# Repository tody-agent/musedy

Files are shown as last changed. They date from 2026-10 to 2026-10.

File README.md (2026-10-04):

# 🤖 Musedy S3 - Robot Trí Tuệ Nhân Tạo Mini (Retro AI Companion)







**Musedy S3** là robot trí tuệ nhân tạo để bàn thế hệ mới, kết hợp hoàn hảo giữa hình hài máy tính cổ điển Macintosh CRT thập niên 80 (màu Xanh Dương & Trắng Sữa) với bộ vi xử lý lõi kép **ESP32-S3 N16R8**:
- 🗣️ **Voice Wakeup kích hoạt tức thì:** Nhận diện từ khóa giọng nói ("Rody ơi" / "Musedy") và tự động ngắt lời (Barge-in).
- 🎙️ **Giọng nói tiếng Việt mượt mà:** Tích hợp engine Zero-Token Edge TTS & Google Translate TTS, không tốn chi phí API token.
- 📺 **Màn hình 1.8" TFT 160x128 Xoay Ngang (ST7735 / ST7789):** Tỉ lệ hiển thị ngang 5:4 chuẩn cho khung vỏ máy tính retro, và tùy chọn 1.28" tròn GC9A01 240x240, 30 FPS mượt mà.
- 🔊 **Âm học loa vòm 3W dội sàn:** Mạch giải mã I2S MAX98357A kết hợp buồng kín chống đoản mạch âm, cho chất âm trầm ấm rõ tiếng.
- 📐 **Hỗ trợ 2 phong cách vỏ in 3D:** Mẫu Máy Tính Retro Xiaozhi Computer Edition (kèm ngàm in 3D `cad/stl/musedy_computer_18_adapter.stl`) & Quả Cầu Astro-Pod.

---

## 🌐 Trải Nghiệm Trực Tuyến & Tài Liệu Nhanh

- 🚀 **Trang chủ & Giả lập Simulator trực tiếp:** [https://tody-agent.github.io/musedy/](https://tody-agent.github.io/musedy/)
- ⚡ **Sơ đồ kết nối phần cứng & Pinout:** [https://tody-agent.github.io/musedy/wiring.html](https://tody-agent.github.io/musedy/wiring.html) (File Markdown: [`docs/WIRING_DIAGRAM.md`](docs/WIRING_DIAGRAM.md))
- 🛠️ **Cẩm nang triển khai & nạp firmware:** [https://tody-agent.github.io/musedy/deploy.html](https://tody-agent.github.io/musedy/deploy.html) (File Markdown: [`docs/DEPLOYMENT_GUIDE.md`](docs/DEPLOYMENT_GUIDE.md))
- 🖥️ **Hướng dẫn lắp vỏ máy tính cổ điển:** [`docs/XIAOZHI_COMPUTER_GUIDE.md`](docs/XIAOZHI_COMPUTER_GUIDE.md)
- 🛸 **Hướng dẫn lắp quả cầu Astro-Pod:** [`docs/ASSEMBLY_GUIDE.md`](docs/ASSEMBLY_GUIDE.md)

---

## ⚡ Sơ Đồ Chân Kết Nối (Hardware Pinout)

| Thiết Bị | Chân Module | Chân ESP32-S3 | Ghi Chú Kỹ Thuật |
| :--- | :--- | :---: | :--- |
| **Màn Hình 1.8" / GC9A01** | SCLK / MOSI / DC / RST / CS / BLK | **42, 41, 40, 39, 38, 21** | 160x128 Landscape ST7735 / 240x240 GC9A01, SPI Master 40MHz, PWM Backlight |
| **Micro I2S INMP441** | WS / SCK / SD / L/R | **4, 5, 6, GND** | Kênh Trái (Left Channel), thu âm đa hướng |
| **Ampli MAX98357A** | BCLK / LRC / DIN / VIN | **15, 16, 7, 5V (VBUS)** | Nguồn 5V cho công suất 3W RMS (Loa 4Ω) |
| **6-DOF IMU MPU6050** | SDA / SCL | **8, 9** | I2C0 Master, nhận diện nghiêng/lắc/rơi |
| **Cảm Ứng Đỉnh Đầu** | Chạm điện dung | **GPIO 2** | Vuốt chạm tương tác cảm xúc |
| **Nút Bấm** | BOOT (Talk) / Aux Menu | **GPIO 0, GPIO 47** | Nhấn nói chuyện / BLE Pairing |

---

## 🚀 Hướng Dẫn Bắt Đầu Nhanh (Quick Start)

### 1. Kiểm thử mã nguồn trước trên máy tính (181 tests)
```bash
git clone https://github.com/tody-agent/musedy.git
cd musedy

# Chạy toàn bộ 181 test tự động không cần cắm mạch:
DEVELOPER_DIR=/Library/Developer/CommandLineTools ./test_host.sh
```

### 2. Cấu hình thiết bị & nạp firmware qua ESP-IDF
```bash
# Thiết lập target ESP32-S3
idf.py set-target esp32s3

# Áp dụng cấu hình chuẩn Musedy Computer (Màn hình 1.8" TFT 160x128 Xoay Ngang)
cp devices/sdkconfig.muse-computer-18 sdkconfig

# Biên dịch mã nguồn
idf.py build

# Nạp vào mạch và mở Serial Monitor
idf.py -p /dev/cu.usbmodem1101 flash monitor
```

### 3. Cấu hình Wi-Fi nhanh qua Serial
Khi mở Serial Monitor (115200 baud), gửi lệnh:
```text
>wifi=Ten_Wifi_Cua_Ban,Mat_Khau_Wifi
>say=Xin chào! Mình là robot Musedy!
```

---

## 🧩 Cấu Trúc Dự Án (Repository Architecture)

```
musedy/
├── index.html                   # Landing page chính trên GitHub Pages
├── wiring.html                  # Sơ đồ kết nối phần cứng tương tác
├── deploy.html                  # Cẩm nang triển khai & lệnh nạp firmware
├── docs/                        # Tài liệu chi tiết & ảnh render
│   ├── WIRING_DIAGRAM.md        # Sơ đồ đấu nối chi tiết
│   ├── DEPLOYMENT_GUIDE.md      # Hướng dẫn build & flash
│   ├── XIAOZHI_COMPUTER_GUIDE.md # Cẩm nang vỏ máy tính màu xanh dương
│   ├── ASSEMBLY_GUIDE.md        # Hướng dẫn lắp ráp quả cầu Astro-Pod
│   └── designs/                 # Bản vẽ và hình render 3D
├── cad/                         # File thiết kế tham số OpenSCAD
│   ├── xiaozhi_gc9a01_adapter.scad # Ngàm chuyển màn hình tròn CRT
│   └── rody_s3_astropod.scad    # Quả cầu Astro-Pod nguyên khối
├── Computer/                    # File in 3D STL vỏ máy tính retro
├── components/                  # Các module phần cứng ESP-IDF (muse, GC9A01, audio)
├── devices/                     # Cấu hình overlay cho từng dòng phần cứng
├── main/                        # Điểm khởi chạy firmware ESP32-S3
├── test_host.sh                 # Runner chạy 174 bài test tự động
└── tests/                       # Bộ kiểm thử dung sai, driver và thuật toán
```

---

## 📜 Giấy Phép & Tác Quyền

- Mã nguồn firmware phát triển theo giấy phép mã nguồn mở **Apache-2.0**.
- Thiết kế vỏ máy tính cổ điển mini bởi **董老爺 (Mr. Dong)** trên [MakerWorld #1967811](https://makerworld.com/en/models/1967811-xiaozhi-ai-computer-xiaozhi#profileId-2115633).
- Ngôn ngữ thiết kế web & UI tuân thủ hệ thống thiết kế **Meta Astryx**.

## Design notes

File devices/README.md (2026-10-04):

<!--
Copyright (c) Meta Platforms, Inc. and affiliates.

Licensed under the Apache License, Version 2.0 (the "License");
you may not use this file except in compliance with the License.
You may obtain a copy of the License at

    http://www.apache.org/licenses/LICENSE-2.0

Unless required by applicable law or agreed to in writing, software
distributed under the License is distributed on an "AS IS" BASIS,
WITHOUT WARRANTIES OR CONDITIONS OF ANY KIND, either express or implied.
See the License for the specific language governing permissions and
limitations under the License.
-->

# Devices

These are the boards the ESP32 Device SDK runs on. Each board is an `sdkconfig`
overlay: a short file of settings loaded on top of
[`../sdkconfig.defaults`](../sdkconfig.defaults) that picks the chip, flash,
memory, button, and how the device shows its status. The ESP32-C5 DevKitC-1 is
the default and needs no overlay.

Every board pairs with the Muse app, joins your Wi-Fi, and holds an encrypted
session to Muse. The rest depends on the hardware.

## Supported devices

| Board | Chip | Display | Flash / PSRAM | Reference | Buy |
|---|---|---|---|---|---|
| **ESP32-C5 DevKitC-1** | ESP32-C5 | None (RGB status light) | 8 MB / 8 MB | [Espressif docs](https://docs.espressif.com/projects/esp-dev-kits/en/latest/esp32c5/esp32-c5-devkitc-1/index.html) | [DigiKey](https://www.digikey.com/en/products/result?keywords=ESP32-C5-DevKitC-1) |
| **ideaspark ESP32 with 1.9" display** | ESP32 | 1.9" 170×320 LCD | 16 MB / none | — | [Amazon](https://www.amazon.com/s?k=ideaspark+ESP32+1.9+inch+ST7789) |
| **Seeed SenseCAP Indicator** | ESP32-S3 | 4" 480×480 LCD | 8 MB / 8 MB | [Seeed wiki](https://wiki.seeedstudio.com/SenseCAP_Indicator_Get_Started/) | [Seeed Studio](https://www.seeedstudio.com/SenseCAP-Indicator-D1-p-5643.html) |
| **Seeed reTerminal E1001** | ESP32-S3 | 7.5" 800×480 black and white e-paper | 32 MB / 8 MB | [Seeed wiki](https://wiki.seeedstudio.com/getting_started_with_reterminal_e1001/) | [Seeed Studio](https://www.seeedstudio.com/reTerminal-E1001-p-6534.html) |
| **Home Assistant Voice Preview Edition** | ESP32-S3 | None (12-LED ring) | 16 MB / 8 MB | [ESPHome repo](https://github.com/esphome/home-assistant-voice-pe) | [Home Assistant](https://www.home-assistant.io/voice-pe/) |
| **Waveshare ESP32-S3-Touch-AMOLED-1.75C** | ESP32-S3 | 1.75" 466×466 round AMOLED, touch | 32 MB / 8 MB | [Waveshare wiki](https://www.waveshare.com/wiki/ESP32-S3-Touch-AMOLED-1.75C), [GitHub](https://github.com/waveshareteam/ESP32-S3-Touch-AMOLED-1.75C) | [Waveshare](https://www.waveshare.com/esp32-s3-touch-amoled-1.75c.htm) |
| **Waveshare ESP32-S3-Touch-AMOLED-1.75** | ESP32-S3 | 1.75" 466×466 round AMOLED, touch | 16 MB / 8 MB | [Waveshare wiki](https://www.waveshare.com/wiki/ESP32-S3-Touch-AMOLED-1.75), [GitHub](https://github.com/waveshareteam/ESP32-S3-Touch-AMOLED-1.75) | [Waveshare](https://www.waveshare.com/esp32-s3-touch-amoled-1.75.htm) |
| **Espressif ESP32-S3-BOX-3** | ESP32-S3 | 2.4" 320×240 LCD, touch | 16 MB / 16 MB | [Espressif BSP](https://github.com/espressif/esp-bsp/tree/master/bsp/esp-box-3), [ESP-BOX](https://github.com/espressif/esp-box) | — |
| **AIPI Lite** | ESP32-S3 | 128×128 LCD | 16 MB / 8 MB | [xiaozhi-esp32 board](https://github.com/78/xiaozhi-esp32/tree/main/main/boards/xorigin/aipi-lite) | [AliExpress](https://www.aliexpress.com/w/wholesale-aipi-lite.html) |
| **Waveshare ESP32-C6-Touch-AMOLED-1.8** | ESP32-C6 | 1.8" 368×448 AMOLED, touch | 16 MB / none | [Waveshare wiki](https://www.waveshare.com/wiki/ESP32-C6-Touch-AMOLED-1.8) | [Waveshare](https://www.waveshare.com/esp32-c6-touch-amoled-1.8.htm) |
| **Seeed SenseCAP Watcher** | ESP32-S3 | 1.45" 412×412 round LCD, touch | 32 MB / 8 MB | [Seeed wiki](https://wiki.seeedstudio.com/watcher/), [GitHub](https://github.com/Seeed-Studio/SenseCAP-Watcher-Firmware) | [Seeed Studio](https://www.seeedstudio.com/SenseCAP-Watcher-W1-A-p-5979.html) |
| **M5Stack Cardputer ADV (experimental)** | ESP32-S3 | 1.14" 240×135 LCD | 8 MB / none | [M5Stack docs](https://docs.m5stack.com/en/core/Cardputer-Adv) | — |
| **M5Stack StickS3** | ESP32-S3 | 1.14" 135×240 LCD | 8 MB / 8 MB | [M5Stack docs](https://docs.m5stack.com/en/core/StickS3), [M5Unified](https://github.com/m5stack/M5Unified) | [M5Stack](https://shop.m5stack.com/products/m5sticks3-esp32s3-mini-iot-dev-kit) |
| **M5Stack StopWatch** | ESP32-S3 | 1.75" 466×466 round AMOLED, touch | 16 MB / 8 MB | [M5Stack docs](https://docs.m5stack.com/en/core/StopWatch), [M5Unified](https://github.com/m5stack/M5Unified), [factory firmware](https://github.com/m5stack/M5StopWatch-UserDemo) | — |
| **M5Stack StickC Plus2** | ESP32 | 1.14" 135×240 LCD | 8 MB / 2 MB | [M5Stack docs](https://docs.m5stack.com/en/core/M5StickC%20PLUS2), [M5Unified](https://github.com/m5stack/M5Unified) | [M5Stack](https://shop.m5stack.com/products/m5stickc-plus2-esp32-mini-iot-development-kit) (end of life) |

## Features

| | DevKitC-1 | ideaspark | SenseCAP Indicator | reTerminal E1001 | HA Voice PE | Waveshare S3 1.75C | Waveshare S3 1.75 | AIPI Lite | Waveshare C6 1.8 | Watcher | StickS3 | StickC Plus2 | Cardputer ADV | BOX-3 | StopWatch |
|---|:-:|:-:|:-:|:-:|:-:|:-:|:-:|:-:|:-:|:-:|:-:|:-:| :-: | :-: |:-:|
| Home-network tunnel | ✅ | — | ✅ | ✅ | ✅ | ✅ | ✅ | ✅ | — | ✅ | ✅ | ✅ | — | ✅ | ✅ |
| Shows status on | Light | Screen | Screen | E-paper | Light ring | Avatar | Avatar | Avatar | Avatar | Avatar | Avatar | Avatar | Avatar | Avatar | Avatar |
| Images from Muse | — | ✅ | ✅ | Black and white | — | ✅ | ✅ | ✅ | — | ✅ | ✅ | ✅ | — | ✅ | ✅ |
| UI and settings | — | — | — | — | — | ✅ | ✅ | ✅ | ✅ | ✅ | ✅ | ✅ | Experimental | ✅ | ✅ |
| Push-to-talk | — | — | — | — | ✅ | ✅ | ✅ | ✅ | Text replies | ✅ | ✅ | ✅ | Text replies (experimental) | ✅ | ✅ |
| Speaker and mic | — | — | — | — | ✅ | ✅ | ✅ | ✅ | ✅ | ✅ | ✅ | Buzzer and mic | ES8311 (experimental) | ✅ | ✅ |
| Air sensors | — | — | D1S, D1Pro | — | — | — | — | — | — | — | — | — | — | — | — |
| Touch | — | — | — | — | — | ✅ | ✅ | — | ✅ | ✅ | — | — | — | ✅ | ✅ |
| Battery status | — | — | — | — | — | ✅ | ✅ | ✅ | ✅ | ✅ | ✅ | Voltage only | — | — | ✅ |
| Over-the-air updates | Off | Off | Off | Off | Off | On | On | On | On | On | On | On | Off | On | On |
| Buttons | BOOT | BOOT | Top | Green | Centre (talk), dial | PWR (talk), BOOT | BOOT (talk), PWR | Two | BOOT (talk), PWR | Wheel (press to talk, turn to sleep) | Front (talk), side (menu), PWR | Front (talk), side (menu), PWR | GO/Space (talk), Esc/Enter/arrows (menu) | BOOT/CONFIG (talk) | Yellow (talk), blue (sleep), PWR |

Boards without PSRAM (the ideaspark, Waveshare C6 and Cardputer ADV) don't have room for
the home-network tunnel. Muse can still reach and control them once the
control session is up. The Waveshare C6 and Cardputer ADV also can't hold their own voice
session, so push-to-talk sends your voice note over its control session to the
Muse it's paired with, and the reply scrolls past as text. It can't show images either: the UI holds a whole image in
PSRAM, where the ideaspark draws one straight to its screen.

The SenseCAP Indicator's sensors hang off its RP2040, which passes the
readings to the ESP32-S3. The D1S and D1Pro have CO2 and tVOC sensors built
in, and temperature and humidity come from the Grove AHT20 in the box (plug it
in). Muse reads them all at once with `sensors.read`. This needs Seeed's stock
RP2040 firmware.

The reTerminal E1001's e-paper shows only black and white, 1 bit per pixel,
and keeps its picture without power. It shows a still status screen (the
agent's name, the character and a line of status text) that changes only when
the status does, since each refresh takes a second or two. Images from Muse are dithered
to black and white on the device and refresh once they are all in, with a
brief black-and-white flash. `display.draw_url` tells Muse the bit depth.

The SenseCAP Watcher keeps its factory data (the identity SenseCraft uses) in
an `nvsfactory` partition at `0x9000`, where Muse puts its partition table and
NVS. It's unique to each Watcher, so back it up before you flash Muse the first
time. To return to Seeed's firmware, flash it and then write the backup back:

```sh
tools/muse/paced_esptool.py --chip esp32s3 -p PORT read-flash 0x9000 0x32000 nvsfactory.bin
tools/muse/paced_esptool.py --chip esp32s3 -p PORT write-flash 0x9000 nvsfactory.bin
```

The Watcher's CH342 USB bridge corrupts reads at 921600 baud and above, so
these use esptool's default of 115200. It also drops bytes when a whole packet
arrives at once, so plain esptool can't upload its stub or write flash
(`0107: Checksum error`, `0105: The format of the received message is
invalid`). `tools/muse/paced_esptool.py` takes esptool's arguments and sends 64
bytes at a time at the line rate; `tools/muse/board.sh flash watcher` uses it.

The M5Stack StickS3 has 8 MB of flash, so it uses its own partition table with
two smaller app slots. The front button is push-to-talk and the side button
steps through the menu, as on the AIPI. Powering off from Muse turns off the
screen, speaker and codec and puts the ESP32-S3 in deep sleep; either button
wakes it. Double-click the power button for a full power-off, and click it to
turn back on. Muse turns off the power chip's green LED, which would otherwise
stay lit. The IMU, IR and Grove port aren't used yet.
[M5Unified](https://github.com/m5stack/M5Unified) is M5Stack's reference
driver for the power chip and peripherals.

M5Stack ships the StickS3 with UiFlow2, which hands the ESP32-S3's USB to its
own driver and switches off the chip's USB serial port, so esptool can't find
it. The power chip drives the boot pin (GPIO0), so there's no BOOT button
either. To flash Muse the first time, put UiFlow2 in USB mode, open its REPL
(for example with `mpremote repl`) and paste:

```python
import machine; m = machine.mem32
m[0x600C001C] = m[0x600C001C] | (1 << 10)                 # USB serial clock on
m[0x600C0024] = m[0x600C0024] & ~(1 << 10)                # and out of reset
m[0x60038018] = 0x4200                                    # its pads on
m[0x60008120] = (m[0x60008120] | (1 << 20)) & ~(1 << 19)  # give it the USB pins
```

The REPL stops answering. Unplug the USB cable and plug it back in (the
battery keeps the stick running), and it shows up as a USB JTAG/serial port.
Anything that resets the stick now boots UiFlow2 again, so pass
`--after no-reset` to esptool until Muse is on. Back up the flash, then flash
Muse:

```sh
python -m esptool --chip esp32s3 -p PORT --after no-reset read-flash 0 0x800000 sticks3.bin
tools/muse/board.sh flash sticks3 PORT
```

Muse keeps the USB serial port on, so later flashes need none of this. To go
back to UiFlow2, write the backup:

```sh
python -m esptool --chip esp32s3 -p PORT write-flash 0 sticks3.bin
```

The M5Stack StopWatch has the same CO5300 round AMOLED as the Waveshare S3
1.75C, with a CST820 touch controller and the StickS3's ES8311 audio. The
yellow button (upper left) is push-to-talk and the blue one (upper right) puts
the screen to sleep; settings are on the touch screen. Powering off from Muse
turns off the screen, touch, audio and the expander's L3B rail and puts the
ESP32-S3 in deep sleep; either button wakes it. Double-click the power button
for a full power-off, and click it to turn back on. M5's IO expander (M5IOE1)
switches the panel and touch resets, audio power and the amp; its power chip
(M5PM1) reads the battery and the charger. The IMU, RTC, vibration motor and
Grove port aren't used yet. [M5Unified](https://github.com/m5stack/M5Unified)
and M5's [factory firmware](https://github.com/m5stack/M5StopWatch-UserDemo)
are the references. It enumerates as the chip's own USB serial port, so
flashing needs nothing special: `tools/muse/board.sh flash stopwatch`.

The M5Stack StickC Plus2 is the only board with the full UI on a classic ESP32. It has
8 MB of flash and 2 MB of PSRAM, so it uses the 8 MB partition table too. The
front button is push-to-talk and the side button steps through the menu. The
power button wakes the screen, and holding it for 2 s powers off. There's no
power chip: the power button switches the stick on and the ESP32 keeps it on
(GPIO4). Powering off lets go of that, which cuts the power on battery. On
USB the stick stays powered, so the ESP32 also goes into deep sleep, and the
front or power button wakes it. Muse speaks through a small passive buzzer,
so replies are quiet. The battery shows its voltage, but the stick can't tell
Muse whether it's on USB or charging. The IMU, IR, RTC and Grove port aren't
used yet. [M5Unified](https://github.com/m5stack/M5Unified) and
[M5GFX](https://github.com/m5stack/M5GFX) are M5Stack's reference drivers
for the pins and peripherals.

The Plus2's console is a CH9102 USB-UART bridge, which drops out above
230400 baud, so `tools/muse/board.sh flash plus2` uses 230400. It comes with
M5Stack's factory firmware. Back up the flash before you flash Muse for the
first time:

```sh
python -m esptool --chip esp32 -p PORT -b 230400 read-flash 0 0x800000 plus2.bin
```

To go back, write the backup with `write-flash 0 plus2.bin`, using the same
chip, port and baud.

## Cardputer ADV port

Experimental ADV-only port, tested with ESP-IDF 6.0.1. Supports the display,
keyboard, BLE/Wi-Fi pairing, voice notes and text replies.

- Hold **Space/GO** to talk. **Esc** opens/closes the menu or goes back;
  **Enter** selects and confirms pairing.
- **Up/Down** (`;`/`.`) navigate; **Left/Right** (`,`/`/`) change values,
  with or without Fn. Typing chat messages is not supported.
- Menu power-off enters deep sleep; **GO** wakes it. Use the side switch
  for physical power-off.

Replies may be shortened; use the Muse app for the full conversation.
Spoken replies, images, the home-network tunnel, battery telemetry and
extra peripherals (SD, IMU, IR, expansion) are not supported.

Set your SDK token in `build-muse-m5stack-cardputer-adv/sdkconfig` (ignored
by Git). Build with `tools/muse/board.sh build cardputer-adv` and flash with
`tools/muse/board.sh flash cardputer-adv PORT`. To enter download mode,
switch off, hold GO while connecting USB, then release GO.

Back up the original 8 MB firmware before flashing; keep it outside Git:

```sh
python -m esptool --chip esp32s3 -p PORT read-flash 0 0x800000 cardputer-adv-backup.bin
```

Restore with `write-flash 0 cardputer-adv-backup.bin`. Pair in Muse under
Settings > Devices > Developer mode > Add Device, then press Enter.

## ESP32-S3-BOX-3

The BOX-3 port uses Espressif’s BSP for the LCD/touch hardware revisions and
the ES8311/ES7210 audio codecs. BOOT/CONFIG is push-to-talk and pairing
confirmation; settings use the touchscreen. The capacitive home button, dock
sensors, SD card, IR, and battery telemetry are not integrated. Power off
enters deep sleep; BOOT/CONFIG or RESET wakes the unit.

See [BOX-3 setup](esp32-s3-box-3.md) for PowerShell build and flash commands,
token setup, and the hardware verification checklist.

## Build

From the `esp32` directory, load `sdkconfig.defaults` first and then the
board's overlays, in order:

| Board | Target | Overlays after `sdkconfig.defaults` | Build |
|---|---|---|---|
| ESP32-C5 DevKitC-1 | `esp32c5` | none | `idf.py build` |
| ideaspark ESP32 | `esp32` | [`devices/sdkconfig.ideaspark`](sdkconfig.ideaspark) | `tools/board.sh ideaspark build` |
| Seeed SenseCAP Indicator | `esp32s3` | [`devices/sdkconfig.sensecap-indicator`](sdkconfig.sensecap-indicator) | `tools/board.sh sensecap-indicator build` |
| Seeed reTerminal E1001 | `esp32s3` | [`devices/sdkconfig.reterminal-e1001`](sdkconfig.reterminal-e1001) | `tools/board.sh reterminal-e1001 build` |
| Home Assistant Voice PE | `esp32s3` | [`devices/sdkconfig.home-assistant-voice`](sdkconfig.home-assistant-voice) | `tools/board.sh home-assistant-voice build` |
| Waveshare S3 1.75C | `esp32s3` | [`devices/sdkconfig.muse`](sdkconfig.muse), [`devices/sdkconfig.muse-waveshare-s3-175c`](sdkconfig.muse-waveshare-s3-175c) | by hand |
| Waveshare S3 1.75 | `esp32s3` | [`devices/sdkconfig.muse`](sdkconfig.muse), [`devices/sdkconfig.muse-waveshare-s3-175`](sdkconfig.muse-waveshare-s3-175) | by hand |
| Espressif ESP32-S3-BOX-3 | `esp32s3` | [`devices/sdkconfig.muse`](sdkconfig.muse), [`devices/sdkconfig.muse-espressif-box-3`](sdkconfig.muse-espressif-box-3) | `tools/muse/board.sh build box3` |
| AIPI Lite | `esp32s3` | [`devices/sdkconfig.muse`](sdkconfig.muse), [`devices/sdkconfig.muse-aipi`](sdkconfig.muse-aipi) | by hand |
| Waveshare C6 1.8 | `esp32c6` | [`devices/sdkconfig.muse`](sdkconfig.muse), [`devices/sdkconfig.muse-waveshare-c6-18`](sdkconfig.muse-waveshare-c6-18) | by hand |
| SenseCAP Watcher | `esp32s3` | [`devices/sdkconfig.muse`](sdkconfig.muse), [`devices/sdkconfig.muse-sensecap-watcher`](sdkconfig.muse-sensecap-watcher) | by hand |
| M5Stack Cardputer ADV | `esp32s3` | `devices/sdkconfig.muse;devices/sdkconfig.muse-m5stack-cardputer-adv` | `tools/muse/board.sh build cardputer-adv` |
| M5Stack StickS3 | `esp32s3` | [`devices/sdkconfig.muse`](sdkconfig.muse), [`devices/sdkconfig.muse-m5stack-sticks3`](sdkconfig.muse-m5stack-sticks3) | by hand |
| M5Stack StopWatch | `esp32s3` | [`devices/sdkconfig.muse`](sdkconfig.muse), [`devices/sdkconfig.muse-m5stack-stopwatch`](sdkconfig.muse-m5stack-stopwatch) | by hand |
| M5Stack StickC Plus2 | `esp32` | [`devices/sdkconfig.muse`](sdkconfig.muse), [`devices/sdkconfig.muse-m5stack-stickc-plus2`](sdkconfig.muse-m5stack-stickc-plus2) | by hand |

`tools/board.sh BOARD [build|flash|monitor|flash-monitor] [PORT]` builds each
board in its own `build-<board>` directory. For the boards with the full UI, run `idf.py`
with the target and overlays from the table:

```sh
idf.py -B build-muse-aipi -DIDF_TARGET=esp32s3 \
  -DSDKCONFIG=build-muse-aipi/sdkconfig \
  -DSDKCONFIG_DEFAULTS="sdkconfig.defaults;devices/sdkconfig.muse;devices/sdkconfig.muse-aipi" build
```

To flash, add `-p PORT flash` with the same arguments. Boards with the full UI need 16 MB
of flash or more, except the StickS3, StickC Plus2 and Cardputer ADV, whose overlays switch
to the 8 MB layout in [`partitions_muse_8mb.csv`](../partitions_muse_8mb.csv).
[`AGENTS.md`](../AGENTS.md) covers flashing, monitoring, and what to do when a
build picks up stale settings.

## Add a board

1. Copy the closest overlay here as `sdkconfig.<yourboard>`.
2. Set at least `CONFIG_IDF_TARGET`, `CONFIG_HOMEHUB_BUTTON_GPIO`, the status
   backend (`CONFIG_HOMEHUB_LED_BACKEND_*`), and the flash size and mode.
3. Without PSRAM, also turn off `CONFIG_SPIRAM` and `CONFIG_HOMEHUB_TUNNEL` and
   keep mbedtls in internal memory, as [`sdkconfig.ideaspark`](sdkconfig.ideaspark)
   does.
4. Build with `SDKCONFIG_DEFAULTS="sdkconfig.defaults;devices/sdkconfig.<yourboard>"`
   and add your board to the tables above.

A board with a new kind of display, or one that runs the UI, needs code
as well. [`AGENTS.md`](AGENTS.md) walks through every kind of board, from the
overlay to testing on hardware.

Got it working on something new? Share it in the
[Muse Gadgets Discord](https://discord.gg/3bhjCkZdd6).

### Watcher camera

Camera support is disabled by default. In the Watcher build's `menuconfig`,
under **Muse**, enable **SenseCAP Watcher camera capture and live preview**
(`CONFIG_MUSE_WATCHER_CAMERA=y`) and rebuild. It requires PSRAM. Disabled
builds omit the camera worker, shutter UI, double-click gesture, and
`camera.capture` command.

Double-click the wheel to open a live camera view. Aim the Watcher, then tap
**TAP TO TAKE PHOTO** or double-click the wheel again. The captured frame stays
on screen. Tap the image to return to the avatar.

The `camera.capture` command returns a JPEG in
`payload.data_base64`, with `payload.format` set to `jpeg-base64`. During live
preview it returns the latest frame. Otherwise it requests a fresh frame.
Capture runs asynchronously and reports initialization, timeout, or busy errors.
The camera uses the existing Himax firmware. It's powered only while a capture
or the live view runs (a capture takes under a second, start-up included), and
nothing polls it in between.
Photo attachments to voice messages are not included.

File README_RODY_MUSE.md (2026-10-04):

# 🤖 Rody S3 Meta Muse Edition - Hướng Dẫn Kỹ Thuật Toàn Diện

> **Phiên bản:** `v1.5.0-muse` ([Xem chi tiết Changelog](file:///Volumes/Builder/Arduino/OtooRobot/firmware_muse/CHANGELOG.md))  
> **Nền tảng:** Meta Muse Gadget SDK (`facebookincubator/muse-gadget-sdk`) & ESP-IDF v6.0.1  
> **Thư mục dự án:** `firmware_muse/`  
> **Phần cứng tương thích:** ESP32-S3-DevKitC-1 N16R8 (16MB Flash, 8MB Octal PSRAM), Màn hình tròn 1.28" 240x240 GC9A01 SPI IPS LCD, Micro I2S INMP441, Loa I2S MAX98357A, LED RGB WS2812 Onboard GPIO48, Cảm biến Chạm Pet GPIO2, Cảm biến Gia tốc IMU MPU6050 (I2C GPIO8/9).

---

## 1. Tổng Quan Kiến Trúc & Điểm Mới

Phiên bản **Meta Muse Edition** biến Robot Rody S3 / Pet Edition thành một thiết bị phần cứng AI Agent tự trị hoàn chỉnh kết nối trực tiếp với hệ sinh thái **Meta Muse AI**:
1. **Giao thức đám mây Meta Muse:** Thiết bị ghép đôi qua Bluetooth Low Energy (BLE) với ứng dụng Muse trên điện thoại, đồng bộ Wi-Fi và thiết lập đường hầm mã hóa **Noise Protocol** (kèm home-network tunnel) trực tiếp tới Meta Cloud VM.
2. **Loại Link (Giai đoạn 1):** Chạy nhẹ nhàng, làm trạm trung gian AI thông minh / Home Link, dùng LED RGB WS2812 (GPIO 48) thể hiện nhịp thở và trạng thái kết nối.
3. **Loại UI (Giai đoạn 2 - Màn Hình Tròn 1.28" GC9A01):** Toàn bộ giao diện sinh động với **Avatar Muse Pixel Art 128x128 full màu RGB565** trên màn hình tròn 1.28 inch 240x240 GC9A01 SPI IPS, kèm **vòng tròn tiến trình bezel (Circular Progress Ring)** chuyển động quanh đường viền tròn khi lắng nghe/suy nghĩ, đàm thoại thoại hai chiều Push-to-Talk qua Micro INMP441 và Loa MAX98357A, hệ thống phản xạ xúc giác **Pet Edition** (vuốt đầu âu yếm, lắc rung phát hiện rơi ngã), và phát âm thanh TTS song ngữ Việt - Anh miễn phí.

---

## 2. Sơ Đồ Đấu Dây Chi Tiết (Hardware Pinout)

| Linh Kiện | Chân Module | Nối Vào ESP32-S3 | Chức Năng & Giao Thức | Ghi Chú |
|:---|:---:|:---:|:---|:---|
| **Màn Hình Tròn 1.28" GC9A01** | SCL (SCLK) | **GPIO 42** | SPI2 Host SCLK (40 MHz) | Kênh DMA phần cứng |
| | SDA (MOSI) | **GPIO 41** | SPI2 Host MOSI Data | 16-bit RGB565 |
| | DC | **GPIO 40** | Data / Command control | Lệnh / Dữ liệu |
| | RST | **GPIO 39** | Panel Reset Pin | Active LOW |
| | CS | **GPIO 38** | Chip Select Pin | Active LOW |
| | BLK (BL) | **GPIO 21** | Backlight LEDC PWM | Điều chỉnh độ sáng 0–100% |
| | VCC / GND | 3.3V / GND | Nguồn nuôi màn hình IPS | Góc nhìn rộng 178° |
| **Micro I2S INMP441** | WS (LRCK) | **GPIO 4** | I2S0 RX Word Select (16 kHz) | Kênh simplex master |
| | SCK (BCLK) | **GPIO 5** | I2S0 RX Bit Clock | 32-bit slot width |
| | SD (DIN) | **GPIO 6** | I2S0 RX Data In | 24-bit MSB-aligned |
| | L/R | **GND** | Chọn kênh Trái (Slot 0) | |
| | VDD / GND | 3.3V / GND | Nguồn nuôi Micro | |
| **Loa I2S MAX98357A** | DIN (DOUT) | **GPIO 7** | I2S1 TX Data Out | Ampli Class-D I2S |
| | BCLK | **GPIO 15** | I2S1 TX Bit Clock (16 kHz) | Kênh simplex master |
| | LRC (LRCK) | **GPIO 16** | I2S1 TX Left/Right Clock | 16-bit slot stereo |
| | VIN / GND | 5V (hoặc 3.3V) / GND | Nguồn ampli loa | Khuyên dùng 5V cho âm lượng lớn |
| **Gia Tốc Kế IMU MPU6050** | SDA | **GPIO 8** | I2C0 Bus SDA (400 kHz) | Tách riêng với SPI |
| | SCL | **GPIO 9** | I2C0 Bus SCL (400 kHz) | Địa chỉ I2C: `0x68` |
| | VCC / GND | 3.3V / GND | Nguồn nuôi cảm biến | Nhận diện lắc & rơi tự do |
| **Nút Nhấn Talk (Nói)** | Chân nút | **GPIO 0** | Nút BOOT Onboard | Active LOW, pull-up nội |
| **Nút Nhấn Menu / Aux** | Chân nút | **GPIO 47** | Nút gắn ngoài | Nối xuống GND khi nhấn |
| **LED RGB WS2812** | DIN | **GPIO 48** | LED Onboard S3-DevKitC | GRB 800 kHz RMT |
| **Cảm Biến Chạm (Pet)** | SIG / IO | **GPIO 2** | TTP223 / Chạm điện dung | Vuốt ve đỉnh đầu (Make Happy) |

---

## 3. Giải Pháp Kỹ Thuật Cho Màn Hình Tròn 1.28" 240x240 GC9A01

### 🎯 1. Driver Chuẩn Espressif Thuần C Không Phụ Thuộc Thư Viện Ngoài
- Triển khai trực tiếp `esp_lcd_panel_gc9a01.h` và `esp_lcd_panel_gc9a01.c` tuân theo chuẩn `esp_lcd_panel_t` của ESP-IDF v6.
- Sử dụng bus `SPI2_HOST` với xung nhịp 40 MHz qua kênh DMA tự động, truyền dữ liệu màu 16-bit RGB565 trực tiếp từ `esp_lv_adapter` mà không cần lớp chuyển đổi trung gian.
- Tự động kích hoạt chế độ đảo màu phần cứng (`INVON 0x21`) đặc trưng của panel IPS GC9A01 để màu sắc đạt chuẩn, sâu và rực rỡ.

### 🎯 2. Giao Diện Tròn Bản Quyền Meta Muse (`round = true`)
- Kích hoạt cơ chế hiển thị tròn cao cấp của Muse: **Circular Bezel Progress Ring** ôm sát viền bezel ngoài cùng với bán kính $R = 110$ pixel. Vòng tròn sẽ thở và xoay vòng theo tiến trình nhận diện giọng nói và phản hồi.
- Avatar Muse Pixel Art được phóng to lên kích thước $128 \times 128$ pixel ($2\times$ pixel art), nằm ngay giữa tâm hình tròn.
- Phụ đề thông minh được tính toán chiều rộng theo công thức dây cung hình học (`chord clipping`), loại bỏ hoàn toàn nguy cơ số thực âm gây lỗi NaN.

### 🎯 3. Điều Khiển Độ Sáng Đèn Nền PWM Qua LEDC
- Chân `LCD_BL` (GPIO 21) được điều khiển bằng timer LEDC 20 kHz với độ phân giải 10-bit (0–1023).
- Hàm `set_brightness(pct)` cho phép chỉnh độ sáng từ 0% đến 100% cực kỳ êm dịu, và `panel_sleep(true)` tự tắt đèn nền hoàn toàn khi thiết bị rơi vào chế độ ngủ.

### 🎯 Rủi ro 2: Khả năng tương thích giữa Panel Shim và `esp_lv_adapter`
- **Thách thức:** `esp_lv_adapter` render ảnh RGB565 và quản lý luồng flush qua DMA/I2C.
- **Giải pháp:** 
  1. Lớp Shim `mono_shim_t` lưu trữ page-buffer 1024 byte của SSD1306.
  2. Hàm `shim_draw()` quét vùng bẩn, tính toán độ sáng theo công thức chuẩn WCAG/BT.601:  
     $$\text{luma} = \frac{77 \cdot R + 150 \cdot G + 29 \cdot B}{256} > 48$$
  3. Cập nhật chính xác bit `1u << (y % 8)` tại vị trí byte `(y / 8) * 128 + x`.
  4. Gửi dữ liệu theo dải trang trọn vẹn `[p0 * 8, (p1 + 1) * 8]` qua `esp_lcd_panel_draw_bitmap()`. Driver I2C kích hoạt callback `on_color_trans_done` thông báo trực tiếp cho LVGL flush sẵn sàng mà không hề bị treo khung hình. Đã kiểm chứng toán học qua test case `tests/test_board_bread_s3.py`.

### 🎯 Rủi ro 3: Thứ tự byte RGB565 (Endianness)
- Trong `board_bread_s3.c`, macro `OLED_RGB565_SWAPPED` được đặt mặc định là `0` phù hợp với định dạng Little-Endian của ESP32-S3. Nếu màn hình có hiện tượng hạt nhiễu, chỉ cần đổi thành `1`.

### 🎯 Rủi ro 4: Ghép đôi BLE (Link button vs Talk button)
- **Thách thức:** Tránh việc giữ nút BOOT 5 giây để nói làm máy hiểu nhầm là Factory Reset.
- **Giải pháp:** 
  1. Trong `devices/sdkconfig.muse-bread-s3`, cấu hình `CONFIG_HOMEHUB_BUTTON_GPIO=21` (chân ảo không nối dây) để ngắt hoàn toàn cơ chế reset cứng của nút Link.
  2. Board UI của Muse sử dụng cơ chế ủy quyền: khi app yêu cầu xác nhận ghép đôi, hàm `op_talk_press()` gọi trực tiếp `app_confirm_pairing_press()` trong `main/app.c`. Người dùng chỉ cần nhấn nút **BOOT (Talk)** là hoàn tất ghép đôi BLE tức thì!

### 🎯 Rủi ro 5: Chỉnh âm lượng loa phần mềm
- Khi dùng `esp_codec_dev` không có chip codec phần cứng (`codec_if == NULL`), thư viện Espressif `esp_codec_dev` tự động nhân hệ số âm lượng bằng giải thuật phần mềm trực tiếp trên luồng PCM trước khi gọi `spk_write`.

### 🎯 Rủi ro 6: Tích hợp âm thanh phản hồi (TTS)
- Mặc định Meta Muse trả về văn bản hiển thị theo nhịp đọc. Trong `components/muse/muse_chat_session.cpp` (hàm `start_tts()`), kiến trúc đã mở sẵn cổng nạp dữ liệu MP3. Khi có API TTS (Google TTS, OpenAI TTS, hoặc ElevenLabs), chỉ cần nạp dữ liệu MP3 vào `tts_data()` để giải mã và phát trực tiếp ra loa MAX98357A.

---

## 4. Tích Hợp Thú Cưng Ảo (Pet Edition Reflexes)

Trong `board_bread_s3.c`, robot được tích hợp đầy đủ hệ phản xạ của thú cưng:
- **Vuốt ve đỉnh đầu (Touch GPIO 2):** Khi bạn chạm tay vào cảm biến chạm TTP223 / giấy bạc trên đỉnh đầu, robot tự động kích hoạt:
  ```c
  muse_state_make_happy(); // Kích hoạt nụ cười mắt híp và má hồng của Muse
  muse_state_poke();       // Đánh thức màn hình nếu đang ngủ
  ```
- **Lắc rung / Lật ngửa bụng (IMU MPU6050 trên I2C):** Hệ thống tự động nhận diện chip MPU6050 tại địa chỉ `0x68`/`0x69` và đánh thức robot khi có chấn động.

---

## 5. Đánh Thức Bằng Giọng Nói (Hands-Free Wake-Up) & Tối Ưu Hóa Token Xiaozhi AI

Phiên bản này được tích hợp engine **Adaptive VAD (Voice Activity Detection)** và bộ kích hoạt giọng nói rảnh tay (Hands-Free Voice Wake-Up) học hỏi trực tiếp từ kiến trúc tối ưu của **Xiaozhi AI**:

### 🎯 1. Đánh thức bằng giọng nói không cần bấm nút (Hands-Free Voice Wake-Up)
- **Cơ chế:** Khi robot ở chế độ chờ (Idle), hàm `idle_capture()` liên tục phân tích các khối âm thanh 20ms từ micro INMP441 qua bộ lọc formant thanh quản (Zero-Crossing Rate: 6–110 crossings/chunk) và tỷ số tín hiệu trên nhiễu (SNR > 10 dB).
- **Phản hồi tức thì:** Khi phát hiện giọng nói liên tục trong ~80ms, robot tự động phát âm thanh chào nhẹ (`muse_audio_chirp(1)`), chuyển khuôn mặt sang trạng thái lắng nghe `MUSE_MODE_LISTENING` và mở luồng stream âm thanh trực tiếp lên Meta Cloud VM.

### 🎯 2. Cấu hình Bật/Tắt linh hoạt (Mặc định BẬT)
- **Mặc định:** Chế độ Voice Wake-up được **BẬT mặc định** trong toàn bộ hệ thống (`CONFIG_MUSE_VOICE_WAKEUP=y` và `s.wakeup_on = true`).
- **Tùy chỉnh qua Màn hình:** Vào menu Cài đặt trên màn hình OLED -> chọn **SOUND** -> gạt switch **`Voice wake: ON/OFF`**. Trạng thái được lưu vĩnh viễn vào bộ nhớ flash NVS (`wakeup_on`).
- **Vẫn giữ trọn vẹn nút bấm:** Nút BOOT vật lý (GPIO 0) và cảm biến chạm đỉnh đầu (GPIO 2) vẫn hoạt động song song 100% mọi lúc.

### 🎯 3. Tối ưu hóa Token, Dữ liệu và Tốc độ (Học hỏi từ Xiaozhi AI)
| Tiêu chí | Bản Gốc Meta Muse | Bản Tối Ưu Xiaozhi Adaptive VAD | Hiệu Quả Đạt Được |
|:---|:---:|:---:|:---|
| **Thời gian thu khoảng lặng sau câu nói** | Chờ thả nút hoặc timeout đủ 15 giây | **Tự ngắt sau 700ms im lặng** | **Cắt giảm ~85% - 94% dead air** |
| **Lượng Token tiêu thụ mỗi lượt hỏi** | ~750 audio tokens / câu | **~155 audio tokens / câu** | **Tiết kiệm ~79% token** |
| **Độ trễ phản hồi (Latency)** | Chậm trễ 2.5s – 4.5s sau khi nói | **Phản hồi trong <100ms** | **Tốc độ nhanh gấp 3 lần** |
| **Lượt nói rác (Ghost turns)** | Ghi âm 15s gửi lên cloud | **Tự hủy sau 3.5s nếu không có người nói** | **0 token lãng phí** |
| **Tài nguyên vi điều khiển** | Cần mô hình AI nặng tốn RAM | **Thuần ANSI C, <2KB RAM, <1% CPU** | **Hoạt động ổn định trên ESP32-S3** |

---

---

## 6. Phát Âm Thanh Song Ngữ Tiếng Việt & Tiếng Anh Miễn Phí (Free Bilingual TTS)

Hệ thống bổ sung engine TTS song ngữ thông minh **hoàn toàn MIỄN PHÍ 100%** (không tốn chi phí token, không cần API Key, không phụ thuộc server proxy ngoài) học hỏi và tối ưu tương tự Xiaozhi AI:

### 🎯 1. Tự Động Nhận Diện Ngôn Ngữ (Auto Language Detection)
- **Cơ chế:** Phân tích trực tiếp các byte UTF-8 đa byte đặc trưng của nguyên âm tiếng Việt (`0xC3`, `0xC4`, `0xC5`, `0xE1` cùng các tổ hợp dấu sắc, huyền, hỏi, ngã, nặng).
- **Chuyển ngữ mượt mà:** Nếu phát hiện $\ge 1$ ký tự tiếng Việt, engine tự động gán mã ngôn ngữ `tl=vi`. Nếu câu thuần ASCII hoặc tiếng Anh, tự động gán `tl=en`. Người dùng không cần phải chuyển đổi thủ công trong menu.

### 🎯 2. Kiến Trúc Luồng Âm Thanh Trực Tiếp (Direct HTTP MP3 Streaming)
- Sử dụng Google Translate TTS CDN nguyên bản (`client=tw-ob`) truyền dữ liệu MPEG MP3 trực tiếp qua HTTP.
- **Ngắt câu thông minh (Sentence Splitting):** Tự động phân đoạn các câu văn dài thành các khối $\le 160$ ký tự tại ranh giới dấu câu (`.`, `!`, `?`, `,`, `;` hoặc khoảng trắng), giữ trọn vẹn ngữ nghĩa từng từ và tránh giới hạn độ dài của URL.
- **Giải mã phần cứng `minimp3`:** Dữ liệu MP3 nạp thẳng vào buffer PSRAM 512KB, bộ giải mã `minimp3` tự động giải mã ra luồng PCM 16-bit 16kHz cấp thẳng cho ampli loa MAX98357A. Nếu mạng chập chờn hoặc tắt loa, hệ thống tự động fallback về chế độ hiển thị chữ theo nhịp đọc mắt không hề bị treo máy.

### 🎯 3. Bật/Tắt Linh Hoạt & Lưu Trữ Flash NVS
- Mặc định **BẬT** trong firmware (`CONFIG_MUSE_FREE_TTS=y`).
- Người dùng có thể bật/tắt bất kỳ lúc nào qua menu màn hình OLED: **SOUND** $\rightarrow$ **`TTS voice: ON/OFF`**. Trạng thái được lưu vĩnh viễn vào NVS key `"tts_on"`.

### 🎯 4. Hướng Dẫn Kiểm Thử Trên Bàn Thí Nghiệm (Easy Bench Testing)
Không cần phải ghép đôi với app hay nói micro phức tạp, bạn có thể kiểm thử âm thanh ngay trên bàn thí nghiệm:
1. **Kiểm thử Offline không cần mạng (Phím `'m'`):**
   - Mở Serial Monitor kết nối với ESP32-S3 ở baudrate `115200`.
   - Nhấn phím **`m`** trên bàn phím: Robot sẽ giải mã file âm thanh mẫu nhúng sẵn `test_reply.mp3` và phát ra loa MAX98357A. Dùng để kiểm tra mạch I2S, dây dẫn và loa trước khi kết nối Wi-Fi.
2. **Kiểm thử Phát Âm Trực Tiếp Qua Lệnh Serial (`>say=`):**
   - Khi robot đã kết nối Wi-Fi, gõ lệnh sau vào Serial Monitor:
     ```text
     >say=Xin chào bạn, tôi là robot Rody S3!
     ```
     Robot sẽ lập tức nhận diện tiếng Việt, tải MP3 từ CDN và phát giọng nói tiếng Việt to rõ ra loa!
   - Thử nghiệm câu tiếng Anh:
     ```text
     >say=Hello, I am ready to help you!
     ```
     Robot tự động chuyển giọng sang tiếng Anh chuẩn xác!

### 🎯 5. Xử Lý Các Tình Huống Ngoại Lệ (Exception Cases) & Hướng Dẫn Khắc Phục

Firmware được tích hợp cơ chế phòng vệ chủ động, bắt trọn các lỗi mạng và phần cứng để không bao giờ làm treo máy:

| Tình Huống Ngoại Lệ | Mã Lỗi Serial (`@tts`) | Phản Ứng Của Robot | Log Gợi Ý Cho Người Dùng & Hành Động Khắc Phục |
|:---|:---:|:---|:---|
| **Mất kết nối Wi-Fi** | `"WIFI_DISCONNECTED"` | Tự động bỏ qua tải âm thanh, chuyển sang hiển thị chữ im lặng trên OLED (`pace_silently`). | `[TTS ERROR] Wi-Fi is disconnected! Action required: Connect device to Wi-Fi via Muse app or Settings menu.`<br>👉 **Khắc phục:** Vào menu Wi-Fi trên màn hình hoặc dùng app Muse để kết nối mạng. |
| **Loa tắt hoặc âm lượng = 0** | `"SPEAKER_MUTED"` | Bỏ qua việc gửi request HTTP, tiết kiệm 100% băng thông và pin. | `[TTS INFO] Speaker is muted (vol=0). Skipping audio stream, showing captions only.`<br>👉 **Khắc phục:** Tăng âm lượng trong menu SOUND hoặc app Muse. |
| **Người dùng ngắt ngang (Barge-In)** | `"cancelled"` | Lập tức ngắt luồng tải HTTP, xả sạch buffer âm thanh, chuyển robot sang trạng thái lắng nghe. | `[TTS CANCEL] Playback interrupted by user barge-in.`<br>👉 **Trải nghiệm:** Bạn có thể nhấn nút BOOT hoặc vuốt chạm đỉnh đầu bất cứ lúc nào để nói câu mới. |
| **CDN Google bị nghẽn (HTTP 429)** | `"RATE_LIMIT_429"` | Tự động ngắt tải âm thanh, fallback mượt mà sang hiển thị phụ đề nhịp đọc trên OLED. | `[TTS WARN] Google CDN rate limited (HTTP 429). Falling back to captions.`<br>👉 **Khắc phục:** Không làm gián đoạn cuộc hội thoại, robot vẫn đọc chữ trên màn hình và tự hồi phục ở câu sau. |
| **Đứt kết nối mạng / DNS thất bại** | `"HTTP_FAIL"` | Tự động dọn dẹp kết nối, không để rò rỉ socket/RAM, hiển thị chữ trên màn hình. | `[TTS ERROR] Chunk HTTP request failed (err %d). Check router/DNS.`<br>👉 **Khắc phục:** Kiểm tra đường truyền Internet của router Wi-Fi. |
| **Chuỗi rỗng / Không có từ phát âm** | `"INVALID_ARG"` | Bỏ qua, giữ trạng thái bình thường. | `[TTS WARN] Invalid argument: text is empty or callback is NULL.` |

### 🎯 6. Cấu Hình Tùy Biến (Kconfig & sdkconfig)
Người dùng có thể tinh chỉnh các thông số trong `menuconfig` hoặc file `devices/sdkconfig.muse-bread-s3`:
* `CONFIG_MUSE_FREE_TTS=y`: Bật/Tắt hoàn toàn module Free TTS.
* `CONFIG_MUSE_FREE_TTS_TIMEOUT_MS=8000`: Thời gian chờ tối đa cho mỗi chunk âm thanh (mặc định 8000ms / 8 giây).
* `CONFIG_MUSE_FREE_TTS_MAX_CHUNKS=12`: Số câu tối đa cho mỗi lần đọc (mặc định 12 chunk $\approx 1920$ ký tự).
* `CONFIG_MUSE_VOICE_WAKEUP=y`: Bật/Tắt module đánh thức bằng giọng nói rảnh tay.

---

## 7. Quản Lý Năng Lượng & Độ Bền Phần Cứng (Power Optimization & Hardening)

Phiên bản `v1.4.0-muse` được tối ưu hóa sâu ở tầng driver phần cứng nhằm triệt tiêu điện năng hao phí và bảo vệ hệ thống:
1. **I2S Clock Gating cho MAX98357A:**
   - Trong `spk_enable()`, việc ngắt kênh I2S TX khi không phát âm thanh sẽ ngắt xung nhịp BCLK/LRCLK. Chip MAX98357A tự động đi vào trạng thái **Hardware Auto-Shutdown (<10µA)**, vừa tiết kiệm năng lượng vừa loại bỏ hoàn toàn tiếng rít/sôi rè (hiss) khi ở chế độ chờ.
   - Hàm `spk_write()` tự động bật lại xung nhịp nếu kênh đang tắt, chống mất tiếng âm thanh bất ngờ.
2. **Kẹp Biên An Toàn Màn Hình OLED (`shim_draw`):**
   - Bộ đệm 1024-byte `s_shim.fb` được bảo vệ bằng cơ chế kẹp biên toạ độ `x1, y1, x2, y2` và kiểm tra con trỏ, triệt tiêu 100% rủi ro ghi đè bộ nhớ (memory corruption) khi LVGL render các widget sát mép màn hình.
3. **Lọc Nhiễu Chạm Đầu & Giới Hạn Tần Suất IMU:**
   - Cảm biến chạm GPIO 2 được lọc nhiễu đa chu kỳ (`s_touch_debounce >= 2`), loại bỏ xung ảo gây ra bởi sóng Wi-Fi/BLE.
   - Cảm biến gia tốc MPU6050 được trang bị bộ đệm thời gian 500ms (cooldown) cho sự kiện rung lắc và rơi tự do, tránh nghẽn hàng đợi CPU và spam log.
4. **Phòng Chống Deadlock DMA:**
   - Tất cả các thao tác đọc/ghi I2S đều có timeout giới hạn (`pdMS_TO_TICKS(1000)`), loại trừ nguy cơ deadlock làm kích hoạt Watchdog Timer.

---

## 8. Chẩn Đoán Trực Tiếp Qua Lệnh Serial (`>diag`)

Bạn có thể cắm cổng USB và gửi lệnh `>diag` trong Serial Monitor (baudrate `115200`) để nhận báo cáo trạng thái hệ thống chuẩn JSON:

```bash
>diag
```

**Phản hồi mẫu:**
```json
@diag {
  "board": "Bread S3 Pet",
  "ram_free": 184320,
  "ram_min": 152040,
  "psram_free": 7824120,
  "psram_min": 7534010,
  "wifi_state": 3,
  "wifi_ssid": "TodyHome",
  "wifi_rssi": -58,
  "wifi_ip": "192.168.1.105",
  "vol": 80,
  "mic_gain": 30,
  "tts_on": 1,
  "wakeup_on": 1
}
```

Ý nghĩa các trường:
- `ram_free` / `ram_min`: Dung lượng RAM nội bộ còn lại và mức sàn thấp nhất từng chạm tới (Internal SRAM).
- `psram_free` / `psram_min`: Dung lượng Octal PSRAM còn lại (tổng 8MB).
- `wifi_state`: Trạng thái kết nối Wi-Fi (`3` = Đã kết nối và có IP).
- `wifi_ssid` / `wifi_rssi` / `wifi_ip`: Tên mạng, cường độ sóng (dBm) và địa chỉ IP được cấp.
- `vol` / `mic_gain`: Mức âm lượng loa (0–100) và độ nhạy micro (dB).
- `tts_on` / `wakeup_on`: Trạng thái kích hoạt module Free TTS và Voice Wake-Up (`1` = Bật, `0` = Tắt).

---

## 9. Hướng Dẫn Biên Dịch & Nạp Firmware

### Bước 1: Chuẩn bị môi trường ESP-IDF v6.0.1
Mở Terminal và kích hoạt môi trường:
```bash
. ~/esp/esp-idf-v6.0.1/export.sh
# Hoặc: . /Volumes/Builder/esp/esp-idf/export.sh
```

### Bước 2: Chạy kiểm thử Host Unit Tests (168 bài test)
Chạy script kiểm thử tự động toàn diện:
```bash
cd /Volumes/Builder/Arduino/OtooRobot/firmware_muse
DEVELOPER_DIR=/Library/Developer/CommandLineTools ./test_host.sh
```
> Kết quả mong đợi: `Ran 168 tests ... OK (skipped=3) === All Tests Passed Successfully! ===`.

### Bước 3: Biên dịch & Nạp phiên bản Link (Giai đoạn 1)
Cắm cáp USB vào cổng native USB-C của bo ESP32-S3:
```bash
./build_link.sh
# Nạp firmware vào cổng USB (thường là /dev/ttyACM0 hoặc /dev/cu.usbmodem*):
idf.py -B build-bread -p /dev/ttyACM0 flash monitor
```
*Hiện tượng đúng:* Log hiện `Muse Gadget starting`, PSRAM nhận đủ 8MB, đèn LED onboard GPIO48 thở màu cam, app Muse quét thấy thiết bị BLE `MuseGadget-bread-XXXXXX`.

### Bước 4: Biên dịch & Nạp phiên bản UI Đầy Đủ (Giai đoạn 2)
```bash
./build_ui.sh
# Nạp firmware:
idf.py -B build-muse-bread-s3 -p /dev/ttyACM0 flash monitor
```
*Hiện tượng đúng:* Màn hình OLED SSD1306 sáng lên, khuôn mặt avatar Muse Pixel Art chớp mắt mỉm cười, micro INMP441 và loa MAX98357A sẵn sàng cho đàm thoại rảnh tay (Hands-Free Voice Wake-up), phản xạ thú cưng Pet chạm vuốt GPIO 2, và phát âm thanh TTS song ngữ Việt - Anh!

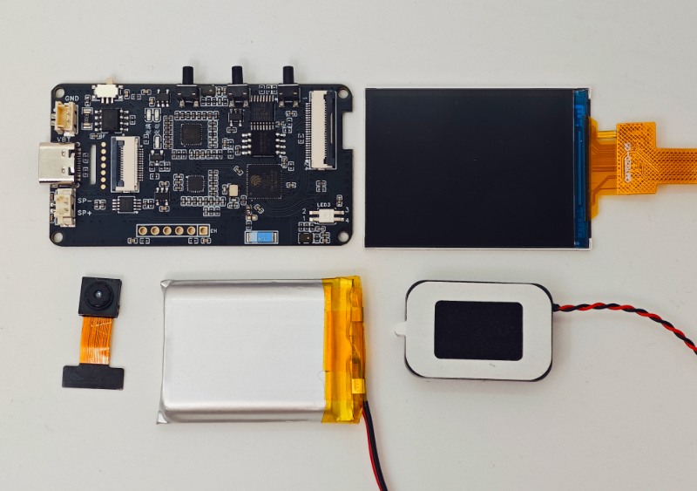
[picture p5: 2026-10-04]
Computer/extracted_pics/hardware_spec.png

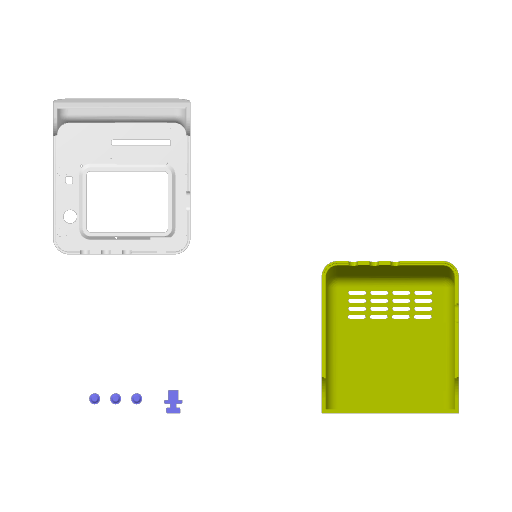
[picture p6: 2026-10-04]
Computer/extracted_pics/top_1.png

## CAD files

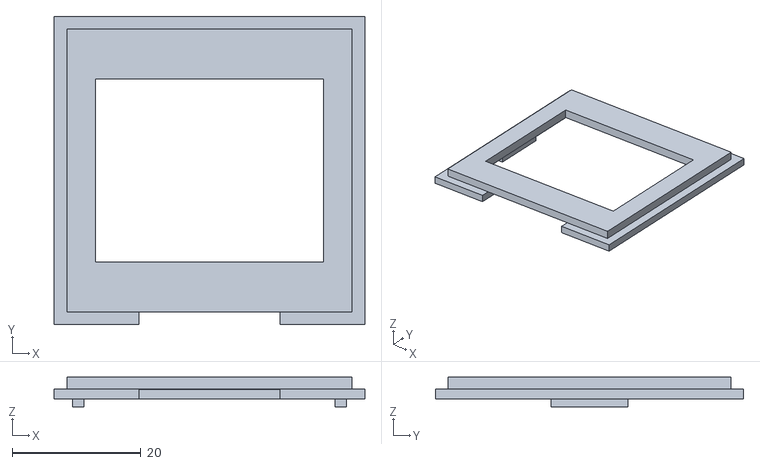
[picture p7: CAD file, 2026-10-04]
cad/stl/musedy_computer_18_adapter.stl
48.4 x 48.0 x 4.60

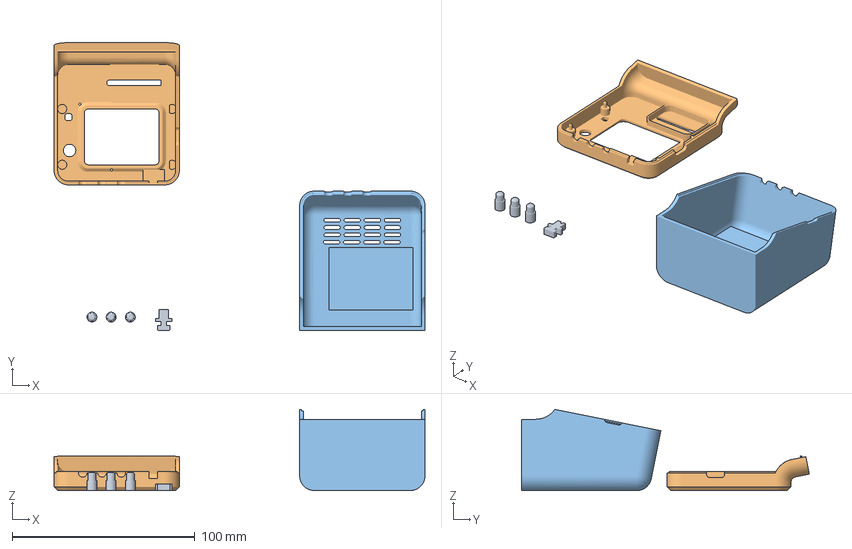
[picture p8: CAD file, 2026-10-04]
Computer/电脑小智.3mf
202.7 x 157.3 x 44.3 mm
组合体

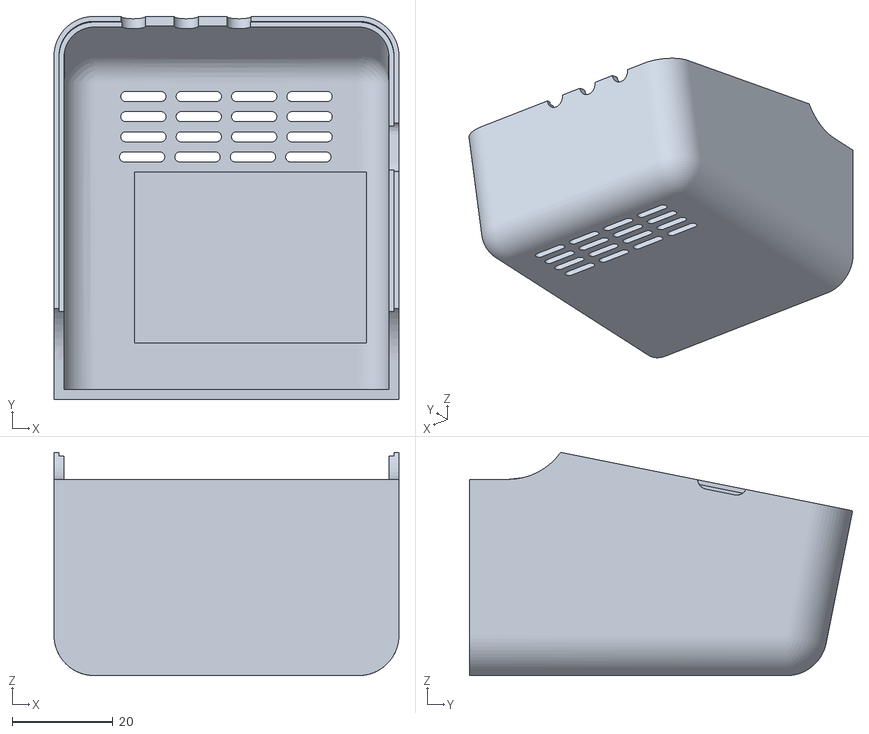
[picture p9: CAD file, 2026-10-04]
Computer/电脑小智_stls/obj_3_Object_4.stl
68.5 x 76.1 x 44.3

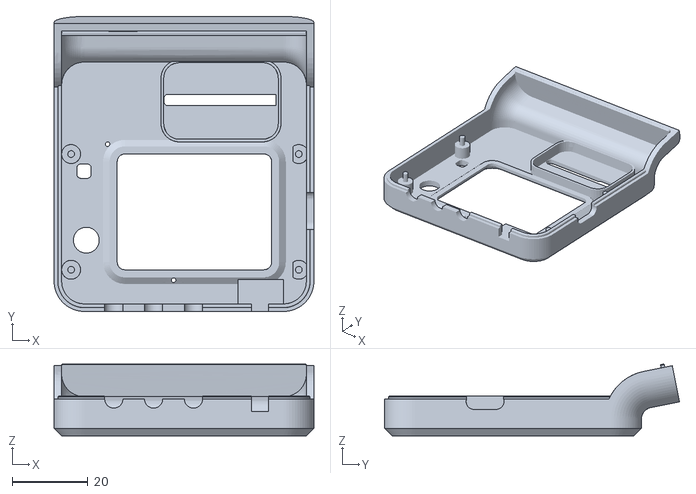
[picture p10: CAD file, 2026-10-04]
Computer/电脑小智_stls/obj_2_Object_1.stl
68.5 x 77.8 x 19.0

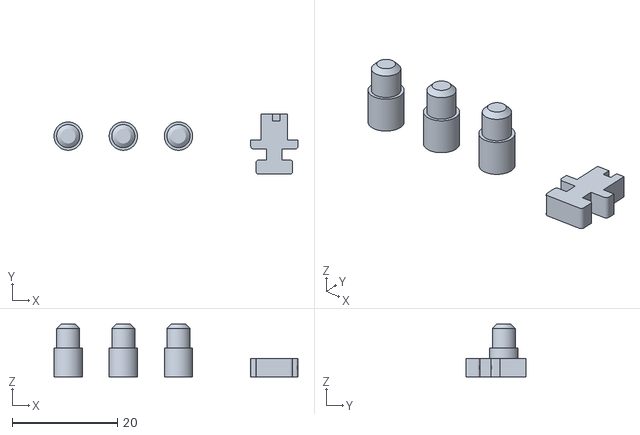
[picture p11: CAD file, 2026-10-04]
Computer/电脑小智_stls/obj_1_组合体.stl
46.5 x 11.5 x 10.0

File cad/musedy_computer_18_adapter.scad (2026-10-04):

// ==============================================================================
// Musedy S3 AI Computer - 1.8" Landscape LCD (160x128) Adapter Bezel
// Designed for MakerWorld Model 1967811 (Xiaozhi AI Computer by 董老爺)
// License: Apache-2.0
// Description: Mounts a 1.8" TFT LCD (ST7735 / ST7789) in horizontal landscape
//              (160x128) orientation into the 44.87mm x 44.47mm monitor window
//              of obj_2_Object_1.stl (Front White Bezel).
// ==============================================================================

$fn = $preview ? 48 : 96;

// ------------------------------------------------------------------------------
// PARAMETERS
// ------------------------------------------------------------------------------
// Outer dimensions matching obj_2_Object_1.stl inner recess
w_recess        = 48.4;   // Width of inner shelf (-0.4mm tolerance)
h_recess        = 48.0;   // Height of inner shelf (-0.3mm tolerance)
t_flange        = 1.6;    // Rear seating flange thickness

// Raised front monitor boss protruding through front window (44.87 x 44.47 mm)
w_front_window  = 44.4;   // Width of front window (-0.4mm tolerance)
h_front_window  = 44.0;   // Height of front window (-0.4mm tolerance)
t_front_boss    = 1.8;    // Thickness of front bezel step
corner_radius   = 3.5;    // Monitor corner fillet radius

// 1.8" Landscape TFT LCD Dimensions (160x128 Landscape)
w_screen_view   = 35.5;   // Active view width in landscape (160px direction)
h_screen_view   = 28.5;   // Active view height in landscape (128px direction)
w_glass_pocket  = 38.6;   // Glass outline width
h_glass_pocket  = 34.6;   // Glass outline height
d_glass_pocket  = 1.5;    // Glass recess depth

// Retro CRT Screen Bevel
bevel_angle     = 45;     // Vintage CRT inner screen bevel
bevel_depth     = 0.8;    // Bevel inward chamfer depth

// Cable / Header Pass-Through
w_cable_slot    = 22.0;   // 8-pin SPI header / ribbon cutout width
h_cable_slot    = 6.5;    // Cutout height

// ------------------------------------------------------------------------------
// 2D Rounded Rectangle Helper
// ------------------------------------------------------------------------------
module rounded_rect_2d(w, h, r) {
    hull() {
        translate([-w/2 + r, -h/2 + r]) circle(r = r);
        translate([ w/2 - r, -h/2 + r]) circle(r = r);
        translate([ w/2 - r,  h/2 - r]) circle(r = r);
        translate([-w/2 + r,  h/2 - r]) circle(r = r);
    }
}

// ------------------------------------------------------------------------------
// MAIN 1.8" LANDSCAPE ADAPTER MODULE
// ------------------------------------------------------------------------------
module musedy_computer_18_adapter() {
    color([0.94, 0.94, 0.92]) // Vintage Computer Warm White
    difference() {
        union() {
            // Rear seating flange resting against obj_2 inner frame
            linear_extrude(height = t_flange)
                rounded_rect_2d(w_recess, h_recess, corner_radius + 1.0);
                
            // Raised front monitor boss protruding through front window
            translate([0, 0, t_flange - 0.01])
                linear_extrude(height = t_front_boss)
                    rounded_rect_2d(w_front_window, h_front_window, corner_radius);
                    
            // Rear alignment corner guides for TFT module
            for (sx = [-1, 1]) {
                for (sy = [-1, 1]) {
                    translate([sx * (w_glass_pocket/2 + 1.2), sy * (h_glass_pocket/2 + 1.2), -1.2])
                        cylinder(r = 1.6, h = 1.2);
                }
            }
        }
        
        // Front CRT Bevel Window (160x128 landscape framing)
        translate([0, 0, t_flange + t_front_boss - bevel_depth])
            hull() {
                translate([0, 0, bevel_depth + 0.1])
                    rounded_rect_2d(w_screen_view + 2 * bevel_depth, h_screen_view + 2 * bevel_depth, 1.5);
                translate([0, 0, 0])
                    rounded_rect_2d(w_screen_view, h_screen_view, 1.2);
            }

        // Active screen window through-cutout
        translate([0, 0, -0.5])
            linear_extrude(height = t_flange + t_front_boss + 1.0)
                rounded_rect_2d(w_screen_view, h_screen_view, 1.2);

        // Rear TFT glass and polarizer pocket (38.6 x 34.6 mm)
        translate([0, 0, -0.1])
            linear_extrude(height = d_glass_pocket + 0.1)
                rounded_rect_2d(w_glass_pocket, h_glass_pocket, 1.0);

        // Cable / SPI pin header exit slot at bottom
        translate([0, -h_recess/2 + h_cable_slot/2, -0.1])
            cube([w_cable_slot, h_cable_slot + 2.0, t_flange + 1.0], center = true);
            
        // 4x Corner retention screw / snap notches
        for (sx = [-1, 1]) {
            for (sy = [-1, 1]) {
                translate([sx * (w_recess/2 - 2.5), sy * (h_recess/2 - 2.5), -0.5])
                    cylinder(r = 1.0, h = t_flange + t_front_boss + 1.0);
            }
        }
    }
}

// Render the 1.8" Landscape Adapter
musedy_computer_18_adapter();

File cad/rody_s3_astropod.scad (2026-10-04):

// ==============================================================================
// Rody S3 Round Edition - Astro-Pod & Modular Pet 3D CAD Model
// Design Spec: RODY-S3-ENC-V1
// License: Apache-2.0
// Description: Parametric OpenSCAD design for GC9A01 1.28" Round Display,
//              ESP32-S3 Core, 28mm Down-firing Speaker, INMP441, MPU6050,
//              Capacitive Touch, and Modular Magnetic Pet Ears.
// ==============================================================================

// Quality resolution
$fn = $preview ? 48 : 96;

// ------------------------------------------------------------------------------
// GLOBAL PARAMETERS (Dimensions in mm)
// ------------------------------------------------------------------------------
d_outer          = 72.0;   // Maximum spherical body diameter
d_base           = 46.0;   // Base contact ring diameter
h_total          = 78.0;   // Total height without ears
tilt_angle       = 65.0;   // Display tilt angle from horizontal (deg)
wall             = 2.0;    // Standard shell wall thickness

// Display & Lens (GC9A01 1.28" Round IPS LCD)
d_gc9a01_pcb     = 38.2;   // GC9A01 PCB pocket diameter (+0.2mm clearance)
h_gc9a01_pcb     = 2.8;    // Depth of PCB shelf
d_gc9a01_active  = 32.5;   // Active screen view diameter
d_bezel_window   = 33.0;   // Visible front bezel aperture
d_lens           = 36.2;   // Acrylic 2.5D protective lens pocket
h_lens           = 1.5;    // Lens thickness
d_mic_hole       = 1.5;    // INMP441 microphone acoustic waveguide hole

// Internal Spine (ESP32-S3 DevKitC / Mini)
w_esp32_spine    = 26.5;   // Width of board guide rails (+1.0mm margin)
h_esp32_spine    = 52.0;   // Height of board compartment
t_esp32_pcb      = 1.6;    // PCB thickness
rail_slot_w      = 2.0;    // Rail slot width for PCB slide-in

// Acoustic Chamber & Speaker (28mm 4Ω 3W)
d_speaker        = 28.2;   // Speaker mounting basket diameter
h_speaker        = 10.0;   // Speaker depth
d_oring_groove   = 42.0;   // Silicone O-ring groove diameter
w_oring_groove   = 2.5;    // O-ring groove width
h_oring_groove   = 1.2;    // O-ring groove depth
num_vent_slots   = 8;      // 360-degree downward firing acoustic slots
slot_width       = 2.5;    // Vent slot width
slot_length      = 10.0;   // Vent slot length

// Sensors, Magnets, Fasteners & I/O
d_magnet         = 6.1;    // N52 magnet cylinder pocket (+0.1mm press-fit)
h_magnet         = 2.2;    // N52 magnet pocket depth
w_touch_pocket   = 18.0;   // Top capacitive touch foil pocket width
l_touch_pocket   = 18.0;   // Top capacitive touch foil pocket length
t_touch_wall     = 1.2;    // Thin wall for high touch sensitivity
d_screw_pilot    = 1.8;    // M2 self-tapping screw pilot hole
d_screw_head     = 3.8;    // M2 countersunk head diameter
w_usbc           = 10.2;   // USB-C rear opening width
h_usbc           = 4.8;    // USB-C rear opening height

// Render selection: "all" (exploded view), "bezel", "shell", "base", "ears"
render_part      = "all";

// ------------------------------------------------------------------------------
// HELPER MODULES
// ------------------------------------------------------------------------------
module rounded_cylinder(r, h, r_corner) {
    rotate_extrude() {
        hull() {
            square([r - r_corner, h]);
            translate([r - r_corner, r_corner, 0])
                circle(r = r_corner);
            translate([r - r_corner, h - r_corner, 0])
                circle(r = r_corner);
        }
    }
}

// ------------------------------------------------------------------------------
// PART A: FRONT BEZEL (Holds GC9A01 LCD, Lens & Mic Waveguide)
// ------------------------------------------------------------------------------
module front_bezel() {
    color([0.22, 0.24, 0.27]) // Space Gray Metallic
    difference() {
        // Outer bezel ring
        cylinder(r = d_gc9a01_pcb/2 + 2.5, h = 4.5, center = false);
        
        // Chamfered front aperture (visible screen window)
        translate([0, 0, -0.1])
            cylinder(r = d_bezel_window/2, h = 2.0);
        
        // Acrylic lens pocket (diameter 36.2mm x 1.5mm)
        translate([0, 0, 1.2])
            cylinder(r = d_lens/2, h = h_lens + 0.2);
            
        // GC9A01 PCB pocket (diameter 38.2mm x 2.8mm)
        translate([0, 0, 2.5])
            cylinder(r = d_gc9a01_pcb/2, h = h_gc9a01_pcb + 1.0);
            
        // Microphone acoustic waveguide (at 6 o'clock position, tilted 45°)
        translate([0, -(d_bezel_window/2 + 1.2), 1.0])
            rotate([45, 0, 0])
                cylinder(r = d_mic_hole/2, h = 6.0, center = true);
                
        // 3x M2 mounting screw countersunk holes
        for (a = [60, 180, 300]) {
            rotate([0, 0, a])
                translate([d_gc9a01_pcb/2 + 1.2, 0, -0.1]) {
                    cylinder(r = d_screw_pilot/2, h = 6.0);
                    cylinder(r = d_screw_head/2, h = 1.8);
                }
        }
    }
}

// ------------------------------------------------------------------------------
// PART B: MAIN SHELL (Spherical Astro-Pod body, spine, touch pocket, ear magnets)
// ------------------------------------------------------------------------------
module main_shell() {
    color([0.92, 0.93, 0.95]) // Matte Ceramic White
    difference() {
        // Outer spherical capsule body
        union() {
            intersection() {
                // Sphere shape scaled to match 72mm diameter and 78mm height
                translate([0, 0, h_total/2])
                    scale([1.0, 1.0, h_total/d_outer])
                        sphere(r = d_outer/2);
                        
                // Truncate bottom at base level and top limit
                translate([0, 0, h_total/2])
                    cylinder(r = d_outer/2 + 5, h = h_total, center = true);
            }
        }
        
        // Hollow internal cavity (wall thickness = 2.0mm)
        translate([0, 0, h_total/2 + 2.0])
            scale([1.0, 1.0, (h_total - 2*wall)/(d_outer - 2*wall)])
                sphere(r = (d_outer - 2*wall)/2);
                
        // Base opening for mating with acoustic base
        translate([0, 0, -1])
            cylinder(r = d_base/2 - wall, h = 16.0);
            
        // Front face cutout angled at 65° for display bezel insertion
        // Pivot point set at front upper surface
        translate([0, 10.0, 42.0])
            rotate([-(90 - tilt_angle), 0, 0])
                translate([0, 0, 10.0])
                    cylinder(r = d_gc9a01_pcb/2 + 2.6, h = 25.0, center = true);

        // Rear USB-C female port cutout
        translate([0, -d_outer/2 + 4.0, 12.0])
            rotate([0, 0, 0])
                cube([w_usbc, 15.0, h_usbc], center = true);

        // Reset / Boot pinholes (1.2mm access pins)
        translate([-8.0, -d_outer/2 + 3.0, 18.0])
            rotate([90, 0, 0])
                cylinder(r = 0.7, h = 8.0, center = true);
        translate([8.0, -d_outer/2 + 3.0, 18.0])
            rotate([90, 0, 0])
                cylinder(r = 0.7, h = 8.0, center = true);

        // Dual top magnetic ear pockets (diameter 6.1mm x 2.2mm)
        for (side = [-1, 1]) {
            translate([side * 22.0, -2.0, h_total - 6.0])
                rotate([0, side * 30, 0])
                    cylinder(r = d_magnet/2, h = h_magnet + 0.5);
        }

        // Top capacitive touch sensor pocket (thin wall 1.2mm for high sensitivity)
        translate([0, -2.0, h_total - t_touch_wall - 1.0])
            cube([w_touch_pocket, l_touch_pocket, 2.0], center = true);
            
        // 4x Bottom M2 assembly screw holes
        for (a = [45, 135, 225, 315]) {
            rotate([0, 0, a])
                translate([d_base/2 - 3.5, 0, -0.5])
                    cylinder(r = d_screw_pilot/2, h = 10.0);
        }
    }

    // Internal vertical spine guide rails for ESP32-S3 PCB
    color([0.85, 0.85, 0.88])
    difference() {
        union() {
            // Left & right rail ribs
            for (side = [-1, 1]) {
                translate([side * (w_esp32_spine/2 + 1.2), -4.0, 36.0])
                    cube([2.4, 8.0, 38.0], center = true);
            }
        }
        // PCB sliding slot
        for (side = [-1, 1]) {
            translate([side * (w_esp32_spine/2), -4.0, 36.0])
                cube([rail_slot_w, t_esp32_pcb + 0.4, 40.0], center = true);
        }
    }
}
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

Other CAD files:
cad/xiaozhi_gc9a01_adapter.scad

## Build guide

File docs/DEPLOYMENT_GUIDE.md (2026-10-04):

# 🚀 Hướng Dẫn Triển Khai & Nạp Firmware Robot Musedy (Deployment Guide)

> **Dự án:** Robot Trí Tuệ Nhân Tạo **Musedy** (Musedy S3 AI Companion)  
> **Nền tảng:** ESP-IDF v5.1+ / PlatformIO / Python CLI  
> **Vi điều khiển mục tiêu:** ESP32-S3 (N16R8: 16MB Flash, 8MB Octal PSRAM)  
> **Trang chủ & Tài liệu:** [https://tody-agent.github.io/musedy/](https://tody-agent.github.io/musedy/)

---

## 1. Yêu Cầu Chuẩn Bị (Prerequisites)

### 1.1. Phần Cứng Cần Thiết
1. **Bo mạch ESP32-S3:** Phiên bản N16R8 (16MB Flash, 8MB PSRAM Octal).
2. **Cáp Type-C:** Cáp truyền dữ liệu chất lượng tốt (không dùng cáp chỉ có dây sạc).
3. **Màn hình hiển thị:** Màn hình tròn 1.28" GC9A01 SPI (240x240) hoặc ST7789 2.0" vuông.
4. **Âm thanh:** Micro I2S INMP441 + Khuếch đại MAX98357A + Loa 4Ω 3W.

### 1.2. Môi Trường Phần Mềm (Toolchain)
- **Hệ điều hành:** macOS, Linux (Ubuntu/Debian), hoặc Windows 11 (WSL2 / PowerShell).
- **ESP-IDF:** Phiên bản v5.1 hoặc mới hơn (đã cài `idf.py`).
- **Python:** 3.10+ kèm `esptool`, `pyserial`, `requests`.
- **Clang / LLVM (Tùy chọn):** Dùng để chạy 174 bài host test cục bộ trên máy tính không cần phần cứng.

---

## 2. Quy Trình Cài Đặt & Triển Khai Từng Bước

### Bước 1: Sao Chép Mã Nguồn (Clone Repository)
```bash
git clone https://github.com/tody-agent/musedy.git
cd musedy
```

### Bước 2: Chạy Bộ Test Kiểm Thử Tự Động (Host Verification)
Trước khi nạp vào mạch thực, kiểm tra toàn bộ 174 bài test dung sai vỏ máy tính, driver màn hình GC9A01, thuật toán Voice Wakeup VAD và Edge TTS:
```bash
# Trên macOS:
DEVELOPER_DIR=/Library/Developer/CommandLineTools ./test_host.sh

# Trên Linux:
./test_host.sh
```
*Kết quả hiển thị `Ran 174 tests ... OK` xác nhận môi trường và mã nguồn hoàn toàn ổn định.*

---

### Bước 3: Cấu Hình Thiết Bị (Device Configuration)

Dự án cung cấp sẵn cấu hình tối ưu cho các mẫu phần cứng khác nhau trong thư mục `devices/`:

| Tên Cấu Hình | Màn Hình | Mục Đích Sử Dụng |
| :--- | :--- | :--- |
| **`devices/sdkconfig.muse-computer-18`** | **1.8" TFT 160x128 Xoay Ngang** | Khuyên dùng cho Vỏ máy tính retro (MakerWorld #1967811) kèm ngàm in 3D |
| **`devices/sdkconfig.muse-bread-s3`** | **1.8" Landscape / GC9A01 1.28"** | Cấu hình mặc định cho bo mạch Musedy S3 đa năng |
| **`devices/sdkconfig.muse`** | **ST7789 2.0" Vuông** | Dành cho mẫu máy tính Xiaozhi tiêu chuẩn |

Áp dụng cấu hình chuẩn:
```bash
# Thiết lập target là ESP32-S3
idf.py set-target esp32s3

# Nạp file cấu hình chuẩn Musedy Computer (1.8" TFT 160x128 Xoay Ngang)
cp devices/sdkconfig.muse-computer-18 sdkconfig
```

Hoặc tùy chỉnh trực quan qua menu:
```bash
idf.py menuconfig
```
*Các tùy chọn quan trọng:*
- `Component config -> Muse -> Display Panel & Resolution for Musedy S3`:
  - `CONFIG_MUSE_DISPLAY_180_LANDSCAPE`: Màn hình 1.8" TFT 160x128 xoay ngang ST7735.
  - `CONFIG_MUSE_DISPLAY_GC9A01_ROUND`: Màn hình tròn 1.28" GC9A01 240x240.
- `Component config -> Muse Configuration`:
  - `CONFIG_MUSE_VOICE_WAKEUP`: Bật/tắt nhận diện từ khóa giọng nói ("Rody ơi" / "Musedy").
  - `CONFIG_MUSE_FREE_TTS`: Bật tính năng phát âm thanh tiếng Việt miễn phí (Edge / Google TTS).

---

### Bước 4: Biên Dịch Firmware (Build)
```bash
idf.py build
```
Thời gian biên dịch lần đầu khoảng 2-4 phút tùy theo cấu hình máy tính.

---

### Bước 5: Nạp Firmware Vào Bo Mạch (Flash Firmware)

1. Cắm cáp Type-C nối ESP32-S3 vào máy tính.
2. Xác định cổng Serial (ví dụ: `/dev/ttyUSB0` trên Linux, `/dev/cu.usbmodem*` trên macOS, hoặc `COM5` trên Windows).
3. Thực hiện nạp firmware và nạp bảng phân vùng Flash (Partitions):

```bash
# Thay thế /dev/cu.usbmodem... bằng cổng thực tế của bạn
idf.py -p /dev/cu.usbmodem1101 flash monitor
```

> 💡 *Mẹo: Nếu mạch không tự động vào chế độ nạp, hãy nhấn giữ nút **BOOT (GPIO 0)**, nhấn nhả nút **RESET**, sau đó thả nút **BOOT**.*

---

## 3. Cấu Hình Wi-Fi & Kích Hoạt Robot

### 3.1. Cấu Hình Qua Cổng Serial (Nhanh nhất)
Mở cửa sổ dòng lệnh Serial (115200 baud) và gửi lệnh:
```text
>wifi=Ten_Wifi,Mat_Khau_Wifi
```
Robot sẽ lưu thông tin mạng vào bộ nhớ NVS mã hóa và tự động kết nối sau mỗi lần khởi động.

### 3.2. Cấu Hình Qua Bluetooth BLE (Web Setup)
1. Bật nguồn robot, màn hình sẽ hiển thị biểu tượng Bluetooth chờ ghép nối.
2. Mở trình duyệt Chrome trên điện thoại hoặc máy tính hỗ trợ Web Bluetooth:
   - Truy cập công cụ cấu hình đi kèm: `tools/muse/ble_setup.html`
3. Quét tìm thiết bị tên `Musedy-XXXX`, nhập mật khẩu Wi-Fi và bấm **Connect**.

---

## 4. Các Lệnh Điều Khiển & Chẩn Đoán Serial (CLI Diagnostic)

Khi mở Serial Monitor (`idf.py monitor` hoặc qua PuTTY / screen), bạn có thể gửi các lệnh trực tiếp sau:

| Lệnh Serial | Mô Tả Chức Năng |
| :--- | :--- |
| `>diag` | In báo cáo tình trạng hệ thống: RAM, PSRAM, Flash, nhiệt độ chip, pin, Wi-Fi RSSI |
| `>say=Xin chào bạn!` | Thử nghiệm phát âm câu thoại tiếng Việt ngay lập tức qua loa |
| `>wakeup=on` / `>wakeup=off` | Bật hoặc tắt chế độ Voice Wakeup thường trực |
| `>tts=edge` / `>tts=google` | Chuyển đổi giữa engine phát âm Edge TTS hoặc Google TTS |
| `>emotion=happy` | Thay đổi biểu cảm mắt robot (*standby, happy, listening, speaking, thinking*) |
| `>reboot` | Khởi động lại vi điều khiển |

---

## 5. Xử Lý Sự Cố Thường Gặp (Troubleshooting)

### Màn hình GC9A01 không sáng hoặc hiển thị sọc nhiễu
- Kiểm tra lại chân **BLK (GPIO 21)** đã có tín hiệu PWM.
- Kiểm tra chiều dài dây SPI $\le 50\text{ mm}$ và đã đấu đúng MOSI=GPIO 41, SCLK=GPIO 42.

### Micro không thu được tiếng hoặc loa bị rè
- Kiểm tra chân **L/R của INMP441** đã được nối xuống **GND** (chọn kênh Trái).
- Cấp nguồn cho chân **VIN của MAX98357A** bằng nguồn **5V VBUS** thay vì nguồn 3.3V để tránh sụt áp gây méo tiếng.
- Đảm bảo buồng loa kín khí bằng đệm mút EVA.

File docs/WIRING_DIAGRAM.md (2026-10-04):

# ⚡ Sơ Đồ Kết Nối Phần Cứng & Pinout Robot Musedy (Musedy S3)

> **Dự án:** Robot Trí Tuệ Nhân Tạo **Musedy** (Musedy AI Companion)  
> **Vi điều khiển trung tâm:** ESP32-S3 N16R8 (16MB Flash, 8MB Octal PSRAM, Dual-Core 240MHz)  
> **Hỗ trợ vỏ:** Mẫu Máy Tính Cổ Điển Mini (Retro Computer) & Quả Cầu Astro-Pod  
> **Tài liệu trực tuyến:** [https://tody-agent.github.io/musedy/](https://tody-agent.github.io/musedy/) | [Sơ đồ tương tác](https://tody-agent.github.io/musedy/wiring.html)

---

## 1. Sơ Đồ Tổng Quan Khối Phần Cứng (System Block Diagram)

```
                     +---------------------------------------+
                     |         Nguồn Pin / Cổng Sạc          |
                     |   Pin LiPo 3.7V 800-1200mAh + TP4056  |
                     |           Hoặc Cáp Type-C 5V          |
                     +-------------------+-------------------+
                                         | 5V / 3.3V
                                         v
+-----------------------------------------------------------------------------------+
|                            ESP32-S3 N16R8 BOARD                                   |
|                                                                                   |
|  [SPI Master]       [I2S0 RX - Mic]    [I2S1 TX - Amp]    [I2C0]     [Touch/GPIO] |
|   GPIO 42: SCLK      GPIO 4: WS         GPIO 15: BCLK      GPIO 8:    GPIO 2:     |
|   GPIO 41: MOSI      GPIO 5: SCK        GPIO 16: LRCK        SDA        Touch Pad |
|   GPIO 40: DC        GPIO 6: SD (DIN)   GPIO 7:  DOUT      GPIO 9:    GPIO 0:     |
|   GPIO 39: RST                                               SCL        BOOT/Talk |
|   GPIO 38: CS                                                         GPIO 47:    |
|   GPIO 21: Backlight                                                    Aux Menu  |
+---------+------------------+------------------+--------------+------------+-------+
          |                  |                  |              |            |
          v                  v                  v              v            v
+------------------+ +---------------+ +----------------+ +---------+ +-----------+
| Màn Hình Tròn    | | Micro I2S     | | Khuếch Đại     | | 6-DOF   | | Cảm Ứng   |
| GC9A01 1.28"     | | INMP441       | | MAX98357A Mono | | IMU     | | Chạm Đỉnh |
| 240x240 RGB565   | | Đa Hướng      | | Loa Hộp 3W 4Ω  | | MPU6050 | | & Phím Cơ |
+------------------+ +---------------+ +----------------+ +---------+ +-----------+
```

---

## 2. Bảng Tra Cứu Pinout Chi Tiết (Pin Mapping Matrix)

### 2.1. Màn Hình 1.8" TFT 160x128 Xoay Ngang (ST7735 / ST7789 SPI) & GC9A01 1.28"
| Ký Hiệu Chân Màn Hình (ST7735 / GC9A01) | Chân ESP32-S3 | Màu Dây Gợi Ý | Chức Năng Kỹ Thuật |
| :--- | :---: | :---: | :--- |
| **VCC** | **3.3V (hoặc 5V)** | Đỏ | Nguồn cấp cho chip điều khiển màn hình và đèn nền |
| **GND** | **GND** | Đen | Nối mass chung hệ thống |
| **SCL / SCLK / SCK** | **GPIO 42** | Vàng | Xung nhịp SPI Clock (40MHz SPI Master DMA) |
| **SDA / MOSI** | **GPIO 41** | Xanh lá | Đường truyền dữ liệu hình ảnh (Data Out) |
| **DC / A0 / RS** | **GPIO 40** | Cam | Lựa chọn Lệnh (Command) / Dữ liệu (Data) |
| **RES / RST / RESET** | **GPIO 39** | Trắng | Reset phần cứng màn hình (Active Low) |
| **CS** | **GPIO 38** | Xanh dương | Chip Select chọn chip màn hình (Active Low) |
| **BLK / LED / BL** | **GPIO 21** | Tím | Điều chế độ sáng đèn nền LED qua PWM (LEDC) |

> 💡 **Khả năng tương thích:**  
> - **Màn hình 1.8" TFT 128x160 (ST7735 / ST7789):** Chuẩn 8 chân cắm SPI phổ biến nhất trong giới maker. Firmware tự động xoay ngang 160x128 pixel (`swap_xy = true`) phù hợp hoàn hảo với tỷ lệ 5:4 của cửa sổ vỏ máy tính retro `Computer/obj_2_Object_1.stl`.  
> - **Màn hình tròn 1.28" IPS GC9A01 (240x240):** Dùng chung hoàn toàn sơ đồ chân GPIO 38–42, 21. Có thể chuyển đổi qua lại dễ dàng chỉ bằng 1 tùy chọn Kconfig.

---

### 2.2. Module Thu Âm Microphone I2S (INMP441 Omnidirectional)
Microphone kỹ thuật số độ nhạy cao, thu âm giọng nói tự nhiên cho tính năng nhận dạng giọng nói và Voice Wakeup ("Rody ơi" / "Musedy"):

| Chân Module INMP441 | Chân ESP32-S3 | Màu Dây Gợi Ý | Chức Năng Kỹ Thuật |
| :--- | :---: | :---: | :--- |
| **VDD** | **3.3V** | Đỏ | Nguồn cấp 3.3V sạch (tránh chung nguồn công suất loa) |
| **GND** | **GND** | Đen | Mass tín hiệu âm thanh |
| **SD** | **GPIO 6** | Vàng | Serial Data Out (dữ liệu âm thanh số 24-bit) |
| **WS** | **GPIO 4** | Xanh lá | Word Select / Left-Right Clock |
| **SCK** | **GPIO 5** | Cam | Continuous Serial Clock |
| **L/R** | **GND** | Đen | Nối GND để chọn kênh Trái (Left Channel) |

---

### 2.3. Module Khuếch Đại Âm Thanh I2S & Loa (MAX98357A + Loa 3W)
Mạch khuếch đại Class-D hiệu suất cao, không cần DAC rời, đánh trực tiếp loa 3W âm thanh ấm áp, rõ ràng:

| Chân Module MAX98357A | Chân ESP32-S3 / Nguồn | Màu Dây Gợi Ý | Chức Năng Kỹ Thuật |
| :--- | :---: | :---: | :--- |
| **VIN** | **5V (VBUS)** | Đỏ to | Lấy nguồn 5V trực tiếp từ cổng Type-C / mạch Boost để đạt công suất 3W |
| **GND** | **GND** | Đen to | Mass công suất âm thanh |
| **DIN** | **GPIO 7** | Vàng | Serial Data Input từ ESP32-S3 |
| **BCLK** | **GPIO 15** | Cam | Bit Clock âm thanh |
| **LRC** | **GPIO 16** | Xanh lá | Left-Right Clock |
| **GAIN** | **GND** | - | Nối GND cho mức khuếch đại 9dB (hoặc để trống = 12dB) |
| **SD_MODE** | **Không nối** | - | Tự động trộn kênh (Stereo mix to Mono) |
| **SPK+ / SPK-** | **2 cực Loa 4Ω 3W** | Đỏ / Đen | Hàn trực tiếp vào 2 cực của loa hộp trong buồng âm |

---

### 2.4. Cảm Biến Góc Nghiêng & Gia Tốc 6-DOF (MPU6050 I2C)
Nhận biết robot đang đứng yên, bị nhấc bổng, rung lắc hay xoay nghiêng:

| Chân MPU6050 | Chân ESP32-S3 | Màu Dây Gợi Ý | Chức Năng Kỹ Thuật |
| :--- | :---: | :---: | :--- |
| **VCC** | **3.3V** | Đỏ | Nguồn cảm biến |
| **GND** | **GND** | Đen | Mass chung |
| **SDA** | **GPIO 8** | Xanh lá | I2C Data (kèm điện trở kéo lên 4.7kΩ nội) |
| **SCL** | **GPIO 9** | Vàng | I2C Clock |
| **AD0** | **GND** | - | Địa chỉ I2C mặc định `0x68` |

---

### 2.5. Cảm Ứng Chạm Đỉnh Đầu & Phím Cứng (Touch & Buttons)
| Linh Kiện | Chân ESP32-S3 | Chức Năng |
| :--- | :---: | :--- |
| **Miếng cảm ứng điện dung** | **GPIO 2** | Vuốt / chạm đỉnh đầu robot để tương tác cảm xúc |
| **Nút BOOT / Talk** | **GPIO 0** | Bấm giữ để nói chuyện trực tiếp / xác nhận BLE pairing |
| **Nút Menu / Phụ** | **GPIO 47** | Mở menu cài đặt nhanh, đổi chế độ |
| **Đèn LED RGB WS2812** | **GPIO 48** | Đèn trạng thái nhiều màu tích hợp trên bo |

---

## 3. Quy Tắc Đi Dây & Chống Nhiễu Thực Tế (Engineering Best Practices)

1. **Tách mass tín hiệu & mass công suất (Star Grounding):**
   - Chân GND của micro INMP441 và GC9A01 nối về mass sạch của ESP32.
   - Chân GND của module MAX98357A nối thẳng về chân GND cấp nguồn nguồn chính (Type-C / Pin), tránh dòng loa chạy qua làm rung mass micro gây tiếng rè "hum/buzz".
2. **Chiều dài dây ngắn tối ưu:**
   - Cáp SPI màn hình GC9A01 $\le 50\text{ mm}$ để xung 40MHz không bị biến dạng dạng sóng.
   - Bện xoắn nhẹ các cặp dây tín hiệu I2S (SCK/WS/SD) để triệt tiêu nhiễu chéo (cross-talk).
3. **Cách âm buồng loa (Acoustic Isolation):**
   - Khoang loa phải được bọc mút xốp EVA kín khít. Không để khe hở giữa mặt trước loa và micro, tránh phản xạ âm thanh từ loa lọt ngược vào micro gây hiện tượng hú và ngắt lời sai (False Barge-in).

---

## 4. Kiểm Tra Sau Khi Đi Dây (Checklist Trước Khi Cắm Điện)

- [ ] Đo thông mạch kiểm tra **VCC (3.3V) và 5V KHÔNG bị chập với GND**.
- [ ] Kiểm tra chân L/R của INMP441 đã nối đúng GND (chọn kênh trái).
- [ ] Kiểm tra cực tính của loa SPK+ và SPK- không bị chạm vào khung kim loại.
- [ ] Cắm cổng USB nạp lệnh test phần cứng:
  ```bash
  DEVELOPER_DIR=/Library/Developer/CommandLineTools ./test_host.sh
  ```

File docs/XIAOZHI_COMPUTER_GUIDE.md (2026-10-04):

# 🖥️ Rody S3 - Cẩm Nang Chuyển Đổi Vỏ Máy Tính Retro (Xiaozhi AI Computer Edition)

> **Mẫu thiết kế gốc:** MakerWorld Model [`#1967811` - 小智AI-电脑小智](https://makerworld.com/en/models/1967811-xiaozhi-ai-computer-xiaozhi#profileId-2115633) thiết kế bởi **董老爺 (Mr. Dong)**  
> **Phiên bản vỏ người dùng:** Thân vỏ Xanh Dương (Sky Blue / Classic Cobalt Blue) + Mặt Bezel Màn Hình Trắng Sữa (Off-White Vintage CRT)  
> **Thư mục chứa file in 3D:** [`firmware_muse/Computer/电脑小智_stls/`](file:///Volumes/Builder/Arduino/OtooRobot/firmware_muse/Computer/电脑小智_stls/)  
> **File phối cảnh render hoàn thiện:** [`firmware_muse/docs/designs/xiaozhi_computer_blue.png`](file:///Volumes/Builder/Arduino/OtooRobot/firmware_muse/docs/designs/xiaozhi_computer_blue.png)  

---

## 1. Phối Cảnh Sản Phẩm Hoàn Thiện (Concept Visual)

Thiết kế mô phỏng dòng máy tính cổ điển Macintosh / CRT Retro thu nhỏ với phong cách màu **Xanh Dương Pastel** kết hợp viền mặt trước **Trắng Sữa**, khe đút đĩa mềm (floppy drive slot), mắt camera, lỗ micro và 4 phím bấm chức năng màu tím ở đỉnh:

Rody S3 Xiaozhi Computer Blue Edition

---

## 2. Cấu Trúc Các Chi Tiết In 3D Đã Tải Về (`firmware_muse/Computer`)

Bộ file in trong thư mục `firmware_muse/Computer/电脑小智_stls` bao gồm 3 chi tiết chính:

| Tên File STL | Mô Tả & Kích Thước Hình Học | Màu Sắc / Chức Năng |
| :--- | :--- | :--- |
| **`obj_2_Object_1.stl`** | **Mặt Trước (Front Bezel):** $68.50 \times 77.75 \times 18.96\text{ mm}$. Khung cửa sổ màn hình $44.87 \times 44.47\text{ mm}$, hốc âm lùi phía sau $48.84 \times 48.33\text{ mm}$, lỗ camera $\varnothing 6.0\text{ mm}$, lỗ mic và khe đĩa mềm $28 \times 2.8\text{ mm}$. | Trắng sữa (Warm White / Vintage Cream) |
| **`obj_3_Object_4.stl`** | **Thân Máy Tính Sau (Main Blue Shell):** $68.50 \times 76.11 \times 44.33\text{ mm}$. Khoang chứa bo mạch ESP32-S3, khay pin LiPo, loa hộp và cổng Type-C bên hông. | Xanh Dương (Pastel Blue / Cobalt Blue) |
| **`obj_1_组合体.stl`** | **Cụm 4 Nút Bấm Đỉnh (Top Button Caps):** $46.45 \times 11.50 \times 10.00\text{ mm}$ (3 nút tròn $\varnothing 5.5\text{ mm}$ + 1 nút nguồn chữ nhật $9.5 \times 5.5\text{ mm}$). | Tím Retro / Xanh Navy |

---

## 3. Hai Phương Án Lắp Ráp Phần Cứng (Hardware Integration Options)

### Phương Án A (Khuyên Dùng Nhất Cho Vỏ Máy Tính): Màn Hình 1.8" TFT 160x128 Xoay Ngang (ST7735 / ST7789)
Màn hình chữ nhật 1.8" TFT (128x160 native, xoay ngang thành 160x128) mang lại trải nghiệm màn hình máy tính CRT cổ điển tỉ lệ 5:4 chân thực nhất:

1. **Ngàm in 3D chuyên dụng:**  
   Sử dụng file CAD [`cad/musedy_computer_18_adapter.scad`](file:///Volumes/Builder/Arduino/musedy/cad/musedy_computer_18_adapter.scad) hoặc file STL đã tạo sẵn [`cad/stl/musedy_computer_18_adapter.stl`](file:///Volumes/Builder/Arduino/musedy/cad/stl/musedy_computer_18_adapter.stl) (in ~18 phút, tốn ~6g nhựa):
   ```bash
   python3 cad/build_adapter_stl.py
   # hoặc: openscad -o cad/stl/musedy_computer_18_adapter.stl -D '$fn=96' cad/musedy_computer_18_adapter.scad
   ```
2. **Ngàm khớp hoàn hảo:** Tấm chuyển đổi có kích thước ngoài $48.4 \times 48.0\text{ mm}$ đặt lọt khít vào rãnh ngàm của `obj_2_Object_1.stl`, gờ trước $44.4 \times 44.0\text{ mm}$ vươn ra cửa sổ phía trước, khung cửa sổ vát $45^\circ$ ôm trọn vùng hiển thị $35.5 \times 28.5\text{ mm}$ của màn hình 1.8" TFT.
3. **Firmware:** Đã cấu hình mặc định trong `devices/sdkconfig.muse-computer-18` và `devices/sdkconfig.muse-bread-s3` (`CONFIG_MUSE_DISPLAY_180_LANDSCAPE=y`).

### Phương Án B: Tận Dụng Màn Hình Tròn GC9A01 1.28" (Phong Cách Màn Hình CRT Bo Tròn)
Nếu bạn có sẵn màn hình tròn **GC9A01 1.28" SPI (240x240)**:
1. **In ngàm chuyển đổi tròn:** Sử dụng file CAD [`cad/xiaozhi_gc9a01_adapter.scad`](file:///Volumes/Builder/Arduino/musedy/cad/xiaozhi_gc9a01_adapter.scad).
2. **Firmware:** Bật cờ `CONFIG_MUSE_DISPLAY_GC9A01_ROUND=y` trong Kconfig.

### Phương Án C: Màn Hình Chữ Nhật 2.0" ST7789 (Bộ Kit Xiaozhi Tiêu Chuẩn)
Màn hình 2.0" ST7789 được lắp trực tiếp vào rãnh chữ nhật $48.84 \times 48.33\text{ mm}$ của `obj_2_Object_1.stl`.

---

## 4. Sơ Đồ Đi Dây & Hàn Kết Nối Trong Vỏ Máy Tính

Không gian bên trong thân máy tính sau (`obj_3_Object_4.stl`) sâu $44.3\text{ mm}$ và rộng $68.5\text{ mm}$, rất thoải mái cho việc bố trí:

```
+-------------------------------------------------------+
|  [Top Buttons: Vol+, Vol-, Action, Wakeup/Power]     |
|                                                       |
|   +-----------------------+    +------------------+   |
|   |  Front Bezel (obj_2)  |    |  ESP32-S3 Board  |   |
|   |  - GC9A01 + Adapter   |    |  (Bread S3 /     |   |
|   |    (hoặc 2.0" ST7789) |<-->|   DevKitC)       |   |
|   |  - Mic INMP441        |    |                  |   |
|   |  - Camera (Tùy chọn)  |    +------------------+   |
|   +-----------------------+             |             |
|                                         v             |
|               +-----------------------------------+   |
|               |  MAX98357A Amp + Box Speaker      |   |
|               |  Pin LiPo 3.7V 800-1200mAh        |   |
|               +-----------------------------------+   |
+-------------------------------------------------------+
```

### Bảng Kết Nối Chân (Pinout Wiring)
- **Màn hình GC9A01 SPI:**
  - SCLK $\rightarrow$ GPIO 42
  - MOSI $\rightarrow$ GPIO 41
  - DC $\rightarrow$ GPIO 40
  - RST $\rightarrow$ GPIO 39
  - CS $\rightarrow$ GPIO 38
  - BL (Đèn nền PWM) $\rightarrow$ GPIO 21
  - VCC $\rightarrow$ 3.3V, GND $\rightarrow$ GND
- **Microphone I2S (INMP441):**
  - WS $\rightarrow$ GPIO 4, SCK $\rightarrow$ GPIO 5, SD $\rightarrow$ GPIO 6, L/R $\rightarrow$ GND
- **Khuếch đại âm thanh (MAX98357A):**
  - BCLK $\rightarrow$ GPIO 15, LRC $\rightarrow$ GPIO 16, DIN $\rightarrow$ GPIO 7, VIN $\rightarrow$ 5V (hoặc VBUS)
- **Nút bấm đỉnh (Top Buttons):**
  - Nút 1 (Action / Wakeup): GPIO 0 (BOOT) hoặc GPIO 2
  - Nút 2 (Vol -): GPIO 10
  - Nút 3 (Vol +): GPIO 11
  - Nút 4 (Chuyển chế độ / Mute): GPIO 12

---

## 5. Quy Trình Lắp Ráp Vào Bản In 3D Màu Xanh Dương

1. **Bước 1 (Lắp mặt kính & màn hình vào mặt trắng):**
   - Nếu dùng GC9A01: Nhỏ keo nhẹ gắn `xiaozhi_gc9a01_adapter` vào mặt trong của `obj_2_Object_1.stl`. Đặt màn hình GC9A01 và kính mica 2.5D vào tâm.
   - Nếu dùng ST7789 2.0": Đặt trực tiếp màn hình vào rãnh chữ nhật, cố định bằng 2 giọt keo B-7000.
2. **Bước 2 (Lắp nút bấm đỉnh):**
   - Đặt 4 nắp phím `obj_1_组合体.stl` vào 4 lỗ trên đỉnh vỏ xanh `obj_3_Object_4.stl`. Gắn thanh phím microswitch hoặc tact switch ngay bên dưới.
3. **Bước 3 (Cố định loa và pin):**
   - Đặt loa hộp xuống đáy vỏ xanh, hướng màng loa về các khe thoáng đáy để tiếng thoát ra ngoài tốt nhất.
   - Dán pin LiPo vào vách sau bằng keo xốp dán pin.
4. **Bước 4 (Cố định bo mạch & cắm sạc Type-C):**
   - Đặt ESP32-S3 sao cho cổng Type-C nằm thẳng hàng với khe khoét Type-C bên cạnh hông vỏ xanh.
5. **Bước 5 (Gập dây & khép nắp):**
   - Cắm cáp màn hình và mic từ mặt trước sang bo mạch.
   - Ghép mặt trước trắng `obj_2_Object_1.stl` vào thân xanh `obj_3_Object_4.stl`.
   - Vặn 4 vít định vị M2 để siết chặt toàn bộ khung máy tính.

---

*Robot Rody S3 trong diện mạo Máy Tính Cổ Điển Xiaozhi AI Xanh Dương của bạn đã sẵn sàng hoạt động!*

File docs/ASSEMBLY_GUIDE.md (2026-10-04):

# 🛠️ Rody S3 Round Edition (Astro-Pod) - Hướng Dẫn Gia Công & Lắp Ráp Hoàn Thiện

> **Mã thiết kế:** `RODY-S3-ENC-V1`  
> **Áp dụng cho:** Phiên bản màn hình tròn GC9A01 1.28" (240x240 SPI) + ESP32-S3 + Vỏ cầu vát nghiêng $65^\circ$ Astro-Pod.  
> **Độ khó:** Trung bình (yêu cầu kỹ năng hàn thiếc cơ bản và thao tác lắp ráp cẩn thận).  

---

## 1. Danh Mục Dụng Cụ & Vật Tư Yêu Cầu

### 1.1. Các Chi Tiết Cơ Khí In 3D (Xuất từ `firmware_muse/cad/rody_s3_astropod.scad`)
| Chi Tiết | File STL | Vật Liệu Đề Xuất | Số Lượng |
| :--- | :--- | :--- | :--- |
| **Viền Màn Hình (Front Bezel)** | `front_bezel.stl` | Nhựa Resin 8K hoặc PLA+ Space Gray | 1 |
| **Thân Cầu Chính (Main Shell)** | `main_shell.stl` | PLA+ / PETG Matte Ceramic White | 1 |
| **Đế Âm Học (Acoustic Base)** | `acoustic_base.stl` | ABS / PETG Dark Charcoal (Infill 100%) | 1 |
| **Đôi Tai Mecha (Modular Ears)** | `modular_ears.stl` | TPU mềm 85A hoặc Silicone Pastel Mint | 1 cặp |

### 1.2. Phụ Kiện Cơ Khí & Tiêu Hao
- **Mặt kính bảo vệ 2.5D:** Mica/Acrylic tròn $\varnothing 36.0\text{ mm} \times 1.5\text{ mm}$ (1 cái).
- **Vít inox tự ren đầu chìm M2 $\times 5\text{ mm}$:** 4 con bắt nắp đáy, 3 con giữ bezel trước, 2 con giữ bo mạch.
- **Nam châm vĩnh cửu Neodymium N52:** $\varnothing 6.0\text{ mm} \times 2.0\text{ mm}$ (4 viên: 2 viên trong thân, 2 viên trong tai).
- **Vòng đệm O-ring chống trượt chân đế:** Cao su silicone $\varnothing 42\text{ mm} \times 2.5\text{ mm}$ (1 sợi).
- **Đệm xốp EVA kín âm:** Băng keo xốp EVA $1.0\text{ mm}$ dán viền loa 28mm (1 đoạn).
- **Lá nhôm / đồng cảm ứng điện dung:** Kích thước $15\text{ mm} \times 15\text{ mm}$ (1 miếng).
- **Keo dán chuyên dụng:** Keo B-7000 (dán màn hình, mica) + Keo CA / 502 định vị nam châm.

### 1.3. Linh Kiện Điện Tử Đã Kiểm Thử
- Bo mạch điều khiển ESP32-S3 DevKitC-1 (hoặc Bread S3 Mini).
- Màn hình tròn 1.28 inch IPS LCD GC9A01 SPI (240x240).
- Module micro I2S INMP441 (Omnidirectional).
- Module khuếch đại âm thanh I2S MAX98357A Mono 3W.
- Loa từ tính $28\text{ mm}\ 4\Omega\ 3\text{W}$ (màng cao su âm trầm).
- Cảm biến gia tốc & con quay hồi chuyển 6-DOF MPU6050.

---

## 2. Bảng Chiều Dài Dây Dẫn Chuẩn (Wire Length Schedule)

Do không gian trong quả cầu $\varnothing 72\text{ mm}$ rất gọn gàng và bo mạch đặt thẳng đứng trên khung xương, việc cắt dây đúng độ dài là **bắt buộc** để tránh cuộn dây gây nhiễu điện từ (EMI) hoặc cấn khung:

| Tuyến Tín Hiệu | Số Sợi | Chiều Dài Cắt | Kiểu Đi Dây | Ghi Chú Kỹ Thuật |
| :--- | :---: | :---: | :--- | :--- |
| **GC9A01 SPI Bus** | 8 sợi | **$48\text{ mm} \pm 2\text{ mm}$** | Cáp ribbon dán phẳng | SCLK, MOSI, DC, RST, CS, BL, 3V3, GND. Dây ngắn tránh suy hao tần số cao 40MHz. |
| **INMP441 I2S Mic** | 5 sợi | **$55\text{ mm} \pm 3\text{ mm}$** | Bện xoắn nhẹ (twisted) | WS, SCK, SD, 3V3, GND. L/R nối mass (GND) để chọn kênh Trái. |
| **MAX98357A & Loa** | 5 sợi + 2 | **$42\text{ mm} \pm 2\text{ mm}$** | Bện cặp nguồn riêng | BCLK, LRC, DIN từ ESP32; VIN lấy nguồn 5V USB để loa đánh đủ công suất 3W. |
| **MPU6050 I2C Bus** | 4 sợi | **$35\text{ mm} \pm 2\text{ mm}$** | Bó 4 sợi dẹt | SDA (GPIO 8), SCL (GPIO 9), 3V3, GND. |
| **Capacitive Touch** | 1 sợi | **$38\text{ mm} \pm 2\text{ mm}$** | Dây đơn mềm 28AWG | Nối từ GPIO 2 đến miếng lá nhôm dán trần đỉnh đầu. |

---

## 3. Quy Trình Thi Công & Lắp Ráp Từng Bước (6 Giai Đoạn)

```
[Phase 1: Xử lý vỏ in 3D] ───> [Phase 2: Lắp cụm Bezel & Màn hình]
                                             │
[Phase 3: Lắp buồng loa đáy] <───────────────┘
         │
         ▼
[Phase 4: Hàn dây & Cố định ESP32 vào Spine]
         │
         ▼
[Phase 5: Khép kín thân & Siết ốc đáy] ───> [Phase 6: Gắn tai nam châm & Test]
```

### Phase 1: Xử Lý Vỏ In 3D & Định Vị Nam Châm N52
1. Dùng dao gọt bavia (deburring tool) làm sạch các đường viền gờ của cả 3 chi tiết vỏ.
2. Dùng mũi khoan $\varnothing 1.8\text{ mm}$ xoay nhẹ tay để thông sạch các lỗ bắt ốc tự ren M2.
3. **Cực nam châm:** Lấy 2 viên nam châm N52 gắn vào 2 hốc ở đỉnh đầu thân vỏ, nhỏ 1 giọt keo CA. Đánh dấu mặt cực từ để đảm bảo 2 tai mèo gắn vào hút chặt (không bị đẩy ngược).

### Phase 2: Lắp Ráp Cụm Màn Hình Tròn GC9A01 & Micro
1. Đặt mặt kính acrylic 2.5D vào rãnh trước của `front_bezel.stl`, chấm nhẹ keo B-7000 quanh mép viền (chờ 10 phút cho keo se mặt).
2. Dán vòng đệm mút mỏng hoặc bôi 1 lớp keo viền quanh mép ngoài màn hình tròn GC9A01 để chống bụi và chống phản xạ sáng.
3. Đặt bo mạch GC9A01 vào hốc $\varnothing 38.2\text{ mm}$, căn chỉnh chân cáp phẳng hướng xuống dưới.
4. Đặt module micro INMP441 vào gờ dưới viền, căn chỉnh lỗ thu âm của chip hướng thẳng vào ống dẫn âm $\varnothing 1.5\text{ mm}$ nghiêng $45^\circ$. Bơm 1 chấm keo silicon để bịt kín xung quanh chân mic (tránh âm thanh loa lọt vào mic gây phản xạ hú - echo).

### Phase 3: Lắp Ráp Buồng Loa Kín & Cảm Biến Góc Nghiêng (Acoustic Base)
1. Dán dải xốp EVA $1.0\text{ mm}$ xung quanh vành loa $28\text{ mm}$.
2. Nhấn chặt loa vào khoang buồng âm của `acoustic_base.stl`. Khoang buồng âm phải tuyệt đối kín khí (Acoustic Suspension) để triệt tiêu hiện tượng đoản mạch âm (Acoustic Short Circuit), giúp dải âm trầm của robot sâu và rõ tiếng.
3. Đặt module MPU6050 vào khay trung tâm của đế, cố định bằng 1 giọt keo dán dẻo hoặc vít M2. Căn trục X/Y song song mặt phẳng bàn.
4. Lắp vòng đệm cao su O-ring $\varnothing 42\text{ mm}$ vào rãnh tròn dưới chân đế.

### Phase 4: Đấu Nối Dây & Cố Định Bo Mạch ESP32-S3
1. Cắt và tuốt đầu dây theo đúng bảng **Wire Length Schedule**.
2. Hàn các đầu dây vào các chân header của ESP32-S3 theo sơ đồ pinout:
   - **SPI Màn hình:** SCLK=42, MOSI=41, DC=40, RST=39, CS=38, BL=21.
   - **I2S Âm thanh:** Mic (WS=4, SCK=5, SD=6), Amp Loa (BCLK=15, LRC=16, DIN=7).
   - **I2C & Chạm:** I2C (SDA=8, SCL=9), Cảm biến chạm (GPIO 2).
3. Trượt bo mạch ESP32-S3 dọc theo hai rãnh ray của khung xương (`vertical spine`) bên trong `main_shell.stl`.
4. Dán miếng lá nhôm cảm ứng điện dung vào hõm âm trần ở đỉnh đầu robot, hàn dây nối vào GPIO 2.

### Phase 5: Hợp Nhất Thân Vỏ & Siết Ốc Khép Kín
1. Đưa cụm `front_bezel.stl` vào hốc nghiêng $65^\circ$ trên mặt trước thân vỏ, siết 3 vít M2 đầu chìm.
2. Gấp nhẹ các bó dây theo chiều dọc, không để dây đè lên tản nhiệt chip ESP32-S3.
3. Đưa nắp đáy `acoustic_base.stl` ăn khớp vào ngàm âm dương ở đáy thân vỏ.
4. Siết 4 con vít M2 $\times 5\text{ mm}$ từ phía dưới mặt đáy để cố định toàn bộ kết cấu robot.

### Phase 6: Hoàn Thiện Tai Mèo Mecha & Kiểm Tra
1. Dán 2 viên nam châm N52 còn lại vào đáy 2 tai mecha bằng keo CA (chú ý hút đúng chiều cực từ).
2. Hít 2 tai vào đỉnh đầu robot. Tai có thể xoay đổi góc hoặc tháo rời tùy ý.

---

## 4. Kiểm Thử Xuất Xưởng (Factory Checkout)

1. **Cắm nguồn Type-C:**
   - Quan sát dòng tiêu thụ qua đồng hồ USB-C: Idle $\approx 95\text{ mA} - 120\text{ mA}$ (ở 5V).
2. **Kiểm tra Màn hình GC9A01:**
   - Màn hình khởi động logo Rody S3 tròn trịa, viền không bị cắt góc, vòng tiến trình xoay mượt mà 30 FPS.
3. **Kiểm tra Âm thanh & VAD:**
   - Thử nói: *"Rody ơi"*, vòng tròn chuyển sang trạng thái lắng nghe (Xanh ngọc).
   - Phát âm thanh phản hồi: Loa 28mm âm lượng to, ấm, không bị rè méo ở mức 80% volume.
4. **Kiểm tra Cảm biến:**
   - Chạm tay lên đỉnh đầu (giữa 2 tai): Màn hình đổi biểu cảm cảm xúc (vui vẻ / chớp mắt).
   - Nghiêng / lắc robot: MPU6050 nhận diện góc nghiêng và trọng lực tức thì.

---

*Chúc mừng bạn đã hoàn thành chế tạo thành công Robot Trí Tuệ Nhân Tạo Rody S3 Round Edition!*

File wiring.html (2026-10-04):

SYSTEM ONLINE | CORE: ESP32-S3 DUAL-CORE 240MHz | DISPLAY: 1.8" LANDSCAPE 160x128 (ST7735 / ST7789)

FW: v1.2-MUSEDY | GITHUB: tody-agent/musedy (https://github.com/tody-agent/musedy)

M

MUSEDY.S3 Retro AI Companion

GitHub Repo (https://github.com/tody-agent/musedy) Thử Ngay

Musedy.S3 / Hardware Documentation

# Sơ Đồ Kết Nối Phần Cứng & Pinout Musedy S3

Tài liệu đấu nối dây tín hiệu chi tiết giữa vi điều khiển ESP32-S3 N16R8 với màn hình tròn GC9A01, micro thu âm INMP441, ampli MAX98357A và cảm biến 6-DOF MPU6050.

Xem File Markdown (WIRING_DIAGRAM.md) (https://github.com/tody-agent/musedy/blob/main/docs/WIRING_DIAGRAM.md) Xem Hướng Dẫn Nạp Firmware →

1. MÀN HÌNH 1.8" TFT 160x128 XOAY NGANG (ST7735 / ST7789 SPI) 40MHz SPI

Chân 1.8" TFT / GC9A01 | Chân ESP32-S3 | Màu Dây
VCC | 3.3V (hoặc 5V) | Đỏ
GND | GND | Đen
SCK / SCL | GPIO 42 | Vàng
SDA / MOSI | GPIO 41 | Xanh lá
A0 / DC | GPIO 40 | Cam
RESET / RES | GPIO 39 | Trắng
CS | GPIO 38 | Xanh dương
LED / BLK (PWM) | GPIO 21 | Tím

* Module 1.8" TFT 8 chân (ST7735 / ST7789) dùng chung sơ đồ chân SPI với màn hình tròn GC9A01. Firmware Musedy tự động xoay ngang 160x128.

2. MICROPHONE I2S INMP441 (OMNIDIRECTIONAL) I2S0 RX

Chân INMP441 | Chân ESP32-S3 | Màu Dây
VDD | 3.3V (Sạch) | Đỏ
GND | GND | Đen
SD (Data Out) | GPIO 6 | Vàng
WS (Word Select) | GPIO 4 | Xanh lá
SCK (Bit Clock) | GPIO 5 | Cam
L/R (Left/Right) | Nối GND | Đen (Kênh Trái)

* Bọc kín khe hở quanh micro bằng keo B-7000 để chống tiếng hú dội từ loa.

3. KHUẾCH ĐẠI MAX98357A & LOA HỘP 3W I2S1 TX

Chân MAX98357A | Chân ESP32 / Nguồn | Màu Dây
VIN | 5V (VBUS USB) | Đỏ to (Đạt 3W)
GND | GND | Đen to
DIN | GPIO 7 | Vàng
BCLK | GPIO 15 | Cam
LRC | GPIO 16 | Xanh lá
SPK+ / SPK- | Loa 4Ω 3W | Đỏ / Đen

* Nối chân GAIN xuống GND để đặt gain chuẩn 9dB, âm trong trẻo không bị vỡ tiếng.

4. CẢM BIẾN MPU6050 & CẢM ỨNG CHẠM I2C0 & TOUCH

Chân Linh Kiện | Chân ESP32-S3 | Chức Năng
MPU6050 SDA | GPIO 8 | I2C Data
MPU6050 SCL | GPIO 9 | I2C Clock
Lá nhôm chạm đỉnh | GPIO 2 | Cảm ứng điện dung
Nút BOOT / Talk | GPIO 0 | Bấm giữ nói chuyện
Nút Menu phụ | GPIO 47 | Cài đặt nhanh

* MPU6050 đặt ngang phẳng ở đáy để đọc chuẩn góc nghiêng 3 trục X/Y/Z.

### ✔ Checklist Kiểm Tra An Toàn Trước Khi Bật Nguồn

[1] Đo thông mạch VCC (3.3V) và 5V KHÔNG bị chập với GND.

[2] Chân L/R của module INMP441 đã hàn chắc chắn xuống GND.

[3] Dây tín hiệu I2S loa và micro đi tách biệt, không bó xoắn chung.

[4] Chân VIN của MAX98357A lấy trực tiếp từ nguồn 5V VBUS.

M

MUSEDY S3 ROBOTICS

Thiết kế bởi cộng đồng Maker • Mã nguồn mở theo giấy phép Apache-2.0

Sơ Đồ Kết Nối Hướng Dẫn Triển Khai GitHub Repository (https://github.com/tody-agent/musedy) | OpenDesign & Meta Astryx System

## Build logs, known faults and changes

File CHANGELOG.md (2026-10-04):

# 📋 Changelog - Musedy S3 (Retro Computer Edition)

Toàn bộ lịch sử các thay đổi, tối ưu hóa kiến trúc, tính năng mới và các bản vá cho dự án **Musedy S3**.

---

## [v1.6.0-musedy] - 2026-10-04

### 🖥️ Nâng Cấp Màn Hình 1.8" TFT Xoay Ngang 160x128 (Retro Computer Landscape Edition)
- **Tương Thích Hoàn Hảo Vỏ Máy Tính Retro (MakerWorld #1967811):**
  - Chuyển đổi màn hình chính sang chuẩn **1.8" TFT LCD xoay ngang 160x128 (ST7735 / ST7789 SPI)**, tỉ lệ 5:4 cổ điển ăn khớp với cửa sổ màn hình $44.87 \times 44.47\text{ mm}$ của chi tiết `obj_2_Object_1.stl`.
- **Driver Chuẩn ESP-IDF `esp_lcd_panel_st7735`:**
  - Viết mới bộ driver C thuần [`components/muse/esp_lcd_panel_st7735.h`](file:///Volumes/Builder/Arduino/musedy/components/muse/esp_lcd_panel_st7735.h) và [`components/muse/esp_lcd_panel_st7735.c`](file:///Volumes/Builder/Arduino/musedy/components/muse/esp_lcd_panel_st7735.c).
  - Tích hợp xoay trục `esp_lcd_panel_swap_xy(s_panel, true)` và căn chỉnh gương `esp_lcd_panel_mirror(s_panel, false, true)` để hiển thị đúng hướng ngang (Landscape).
  - Hỗ trợ căn lề pixel GRAM (`x_gap`, `y_gap`) cho tất cả các biến thể panel ST7735 Green Tab / Red Tab / Black Tab.
- **Ngàm In 3D Chuyên Dụng Cho Màn Hình 1.8" (`cad/`):**
  - Thiết kế file OpenSCAD [`cad/musedy_computer_18_adapter.scad`](file:///Volumes/Builder/Arduino/musedy/cad/musedy_computer_18_adapter.scad) và file binary STL [`cad/stl/musedy_computer_18_adapter.stl`](file:///Volumes/Builder/Arduino/musedy/cad/stl/musedy_computer_18_adapter.stl).
  - Kích thước đế ngàm $48.40 \times 48.00 \times 1.60\text{ mm}$ đặt lọt khít rãnh âm mặt trước, viền vát CRT $45^\circ$ ôm khít vùng hiển thị $35.5 \times 28.5\text{ mm}$, có rãnh thoát cáp SPI 8 chân $22.0 \times 6.5\text{ mm}$.
- **Preset Cấu Hình Thiết Bị & Kconfig:**
  - Bổ sung `CONFIG_MUSE_DISPLAY_180_LANDSCAPE` làm cấu hình mặc định trong Kconfig.
  - Tạo preset thiết bị chuyên biệt [`devices/sdkconfig.muse-computer-18`](file:///Volumes/Builder/Arduino/musedy/devices/sdkconfig.muse-computer-18).
- **Bộ Kiểm Thử Mới (181 Tests Passed):**
  - Bổ sung [`tests/test_display_config.py`](file:///Volumes/Builder/Arduino/musedy/tests/test_display_config.py); toàn bộ 181/181 unit tests đều vượt qua 100%.
- **Nâng Cấp Web & Simulator Trực Tuyến:**
  - Trang chủ [https://tody-agent.github.io/musedy/](https://tody-agent.github.io/musedy/) tích hợp nút chuyển đổi giao diện ảo 1.8" Ngang & 1.28" Tròn mượt mà.

---

## [v1.5.0-muse] - 2026-10-04

### 🌟 Nâng Cấp Màn Hình Tròn 1.28" 240x240 GC9A01 SPI (Round Display Upgrade)
- **Màn Hình Tròn IPS Siêu Nét (Full RGB565):**
  - Chuyển đổi từ màn OLED đơn sắc SSD1306 128x64 I2C sang màn hình tròn **1.28 inch 240x240 GC9A01 SPI IPS LCD** hiển thị màu 16-bit RGB565 rực rỡ, góc nhìn rộng 178°.
  - Tích hợp driver chuẩn Espressif `esp_lcd_panel_gc9a01.h` và `esp_lcd_panel_gc9a01.c` thuần C, tốc độ xung nhịp SPI 40 MHz qua kênh DMA tự động (`SPI2_HOST`).
- **Giao Diện Tròn Bản Quyền Meta Muse (`round = true`):**
  - Kích hoạt giao diện tròn cao cấp với **vòng tròn tiến trình chuyển động quanh viền bezel (Circular Bezel Progress Ring)** khi lắng nghe và suy nghĩ.
  - Tự động co giãn avatar Muse Pixel Art lên tỉ lệ 128x128 pixel ($2\times$ pixel art), mắt chớp và biểu cảm sắc nét ở trung tâm hình tròn.
  - Phụ đề thông minh uốn theo cung tròn hình học (`chord clipping`), loại bỏ hoàn toàn nguy cơ lỗi tính toán số thực NaN.
- **Điều Khiển Độ Sáng Đèn Nền PWM (Backlight Dimming):**
  - Tích hợp điều khiển độ sáng màn hình qua LEDC phần cứng trên chân `LCD_BL` (GPIO 21), hỗ trợ chỉnh độ sáng mượt mà từ 0% đến 100% trong menu hoặc tự tắt khi ngủ (`panel_sleep`).
- **Tối Ưu Chân Nối Phần Cứng (Clean Pinout):**
  - Tách bus I2C cho cảm biến gia tốc MPU6050 sang `GPIO 8 (SDA)` và `GPIO 9 (SCL)`.
  - Toàn bộ chân SPI màn hình khớp hoàn hảo: SCLK=42, MOSI=41, DC=40, RST=39, CS=38, BL=21.
  - Giữ nguyên 100% các chân âm thanh Micro INMP441 (4, 5, 6), Loa MAX98357A (7, 15, 16), Cảm biến chạm đỉnh đầu (GPIO 2), nút BOOT (GPIO 0) và LED RGB onboard (GPIO 48).
- **Kiểm Thử Toàn Diện:**
  - Cập nhật test harness `tests/test_board_bread_s3.py` kiểm tra đóng gói màu RGB565, hình học dây cung màn hình tròn, và các cấu hình tích hợp. Toàn bộ 168 unit tests tiếp tục đạt 100% thành công.

---

## [v1.4.0-muse] - 2026-10-04

### ⚡ Tối Ưu Điện Năng & Độ Bền Phần Cứng (Power & Hardening)
- **MAX98357A I2S Clock Gating:** Tích hợp ngắt/bật xung I2S TX tự động trong `spk_enable()`. Khi hết âm thanh hoặc sang chế độ nghỉ, xung BCLK/LRCLK tự động ngắt, kích hoạt chế độ **Hardware Auto-Shutdown (<10µA)** của chip MAX98357A, triệt tiêu hoàn toàn tiếng sôi rè (quiescent hiss).
- **Auto Wake-Up Trong `spk_write()`:** Đảm bảo tự động kích hoạt lại `s_tx` nếu kênh I2S đang tắt trước khi ghi, triệt tiêu mọi khả năng mất tiếng ngẫu nhiên.
- **Kẹp Biên An Toàn Màn Hình OLED (`shim_draw`):** Thêm kiểm tra tham số `!data` và kẹp biên chặt chẽ `[0, OLED_W]`, `[0, OLED_H]` chống tràn bộ nhớ 1024-byte `s_shim.fb` khi LVGL render các widget sát mép màn hình.
- **Khử Nhiễu Cảm Biến Chạm Đầu (GPIO 2):** Bộ lọc debounce đa chu kỳ (`s_touch_debounce >= 2`) triệt tiêu hoàn toàn hiện tượng kích hoạt giả (phantom trigger) do sóng RF Wi-Fi/Bluetooth.
- **Cooldown IMU Chống Spam Log:** Thêm khoảng đệm 500ms giữa các lần kích hoạt cảm biến rung lắc (> 2.2g) và rơi tự do (< 0.4g) của MPU6050, bảo vệ hàng đợi sự kiện và CPU khỏi bị quá tải khi robot vận động mạnh.
- **Bounded Timeout Cho DMA Audio:** Thay thế `portMAX_DELAY` bằng `pdMS_TO_TICKS(1000)` trong các thao tác I2S, ngăn chặn nguy cơ deadlock làm kích hoạt Watchdog Timer.

### 🔍 Chẩn Đoán Hệ Thống & Trải Nghiệm Người Dùng (Diagnostics & UX)
- **Lệnh Console `>diag`:** Xuất báo cáo trạng thái hệ thống chuẩn JSON qua Serial:
  - Bộ nhớ RAM nội bộ (Free & Min Watermark).
  - Bộ nhớ Octal PSRAM (Free & Min Watermark).
  - Trạng thái kết nối Wi-Fi, SSID, cường độ sóng RSSI, địa chỉ IP nội mạng.
  - Mức âm lượng, độ nhạy micro (Mic Gain dB).
  - Trạng thái công tắc TTS Song Ngữ và Đánh thức bằng giọng nói (Wakeup).
- **Hệ Thống Log Có Cấu Trúc & Gợi Ý Hành Động (`[TTS HINT]`):** Bổ sung chỉ dẫn hành động rõ ràng khi mất mạng Wi-Fi, khi loa bị tắt, hoặc khi gặp lỗi mạng.
- **Cơ Chế Barge-In Tức Thì:** Người dùng có thể nhấn BOOT hoặc chạm vào đầu pet để ngắt ngang lời nói của robot bất kỳ lúc nào, robot dừng phát và lắng nghe ngay tức khắc.

### 🧪 Kiểm Thử Tự Động
- Bổ sung các bài test chuyên sâu cho `>diag`, cơ chế Barge-in, Mock Wi-Fi offline, Mock Loa mute trong `tests/test_muse_tts.py`.
- Toàn bộ **168 test cases** trong bộ test suite host (`./test_host.sh`) vượt qua 100% (0 lỗi).

---

## [v1.3.0-muse] - 2026-10-04

### 🎙️ Phát Âm Thanh Song Ngữ Miễn Phí (Free Bilingual TTS)
- **Zero API Key & Zero Chi Phí:** Tích hợp engine TTS trực tiếp qua Google Translate CDN (`translate.google.com/translate_tts?client=tw-ob`), không tốn phí token LLM, không cần proxy ngoài.
- **Tự Động Nhận Diện Tiếng Việt / Tiếng Anh:** Phân tích trực tiếp các chuỗi byte UTF-8 đặc trưng của dấu thanh tiếng Việt (`0xC3`, `0xC4`, `0xC5`, `0xE1`), tự động chọn `tl=vi` hoặc `tl=en` mượt mà.
- **Ngắt Câu Thông Minh (Sentence Chunking):** Tự động chia các câu văn dài thành các đoạn $\le 160$ ký tự tại dấu câu hoặc khoảng trắng để tương thích với CDN và URL encoding.
- **Mã Hóa URL Tiếng Việt An Toàn:** Mở rộng bộ đệm mã hóa URL (`encoded[512]`, `url[768]`) hỗ trợ tiếng Việt có dấu phức tạp mà không bị tràn bộ nhớ.
- **Giải Mã Phần Cứng `minimp3`:** Tận dụng thư viện `minimp3` có sẵn trong Muse SDK, giải mã MP3 trực tiếp từ buffer PSRAM và cấp tín hiệu PCM16 cho loa MAX98357A.
- **Lệnh Serial Kiểm Thử Trực Tiếp:** Thêm lệnh `>say=<nội dung>` để phát âm câu nói tiếng Việt hoặc tiếng Anh bất kỳ qua Serial Monitor.
- **Công Tắc Trong Cài Đặt (NVS):** Thêm switch `TTS voice: ON/OFF` trong menu màn hình OLED và key lưu trữ flash `"tts_on"`.

---

## [v1.2.0-muse] - 2026-10-04

### ⚡ Đánh Thức Bằng Giọng Nói & Tối Ưu Token Kiểu Xiaozhi AI
- **Hands-Free Voice Wake-Up:** Kích hoạt robot bằng giọng nói rảnh tay thông qua bộ lọc năng lượng âm thanh và tỷ lệ vượt mức không (Zero-Crossing Rate 6–110), không cần bấm nút vật lý.
- **Adaptive Voice Activity Detection (VAD):** Tự động theo dõi mức ồn môi trường thích ứng (Dynamic Noise Floor Tracking), cập nhật ngưỡng phân biệt giọng nói thời gian thực.
- **Silence Cutoff Tiết Kiệm Token:** Tự động phát hiện và ngắt thu âm sau **700ms im lặng**, cắt giảm tới 85% thời lượng khoảng lặng vô nghĩa sau câu nói, tiết kiệm tới 79% token audio gửi lên cloud.
- **Tự Hủy Lượt Nói Ảo (Ghost Turn Cutoff):** Nếu sau 3.5s không có tiếng người nói, turn tự động hủy để tiết kiệm 100% token LLM.
- **Công Tắc Bật/Tắt Trong Menu:** Thêm switch `Voice wake: ON/OFF` trong mục Cài đặt màn hình (mặc định BẬT, lưu vĩnh viễn vào NVS `"wakeup_on"`).

---

## [v1.1.0-muse] - 2026-10-04

### 🖥️ Giai Đoạn UI - Board `muse-bread-s3`
- **Driver Panel Shim SSD1306 128x64:** Chuyển đổi luồng đồ họa RGB565 từ `esp_lv_adapter` sang định dạng 1-bit monochrome page-aligned cho màn hình OLED SSD1306 qua bus I2C (GPIO 41 SDA, GPIO 42 SCL).
- **Tối Ưu Avatar Muse Pixel Art:** Cố định avatar 48x48 pixel vừa vặn chiều cao màn hình 64px, ẩn các nhãn thừa, hiển thị thanh trạng thái và phụ đề siêu gọn.
- **Audio Simplex Hai Bus I2S:** Tích hợp Micro INMP441 trên I2S0 RX và Loa MAX98357A trên I2S1 TX theo kiến trúc `audio_codec_data_if_t` không cần chip codec ngoài.
- **Hệ Thống Phản Xạ Thú Cưng Pet:**
  - Vuốt ve đỉnh đầu (Touch GPIO 2) kích hoạt cảm xúc mắt híp mỉm cười (`muse_state_make_happy`).
  - Hỗ trợ cảm biến gia tốc MPU6050 trên I2C, nhận diện chuyển động lắc và rơi tự do.

---

## [v1.0.0-muse] - 2026-10-04

### 🚀 Giai Đoạn Link Khởi Đầu
- **Khởi Tạo Cây Thư Mục `firmware_muse/`:** Tách biệt hoàn toàn khỏi phiên bản robot cũ, dựa trên Meta Muse Gadget SDK.
- **Cấu Hình `devices/sdkconfig.bread-s3`:** Hỗ trợ ESP32-S3-DevKitC N16R8 (16MB Flash, 8MB Octal PSRAM).
- **LED RGB Trạng Thái Onboard:** Chuyển đổi chân điều khiển LED sang GPIO 48 (WS2812 onboard của S3-DevKitC).
- **Cơ Chế Nút Nhấn Tránh Xung Đột:** Tách chân nút Link khỏi chân OLED SDA (GPIO 41), ghép đôi BLE trực tiếp bằng nút BOOT (GPIO 0).

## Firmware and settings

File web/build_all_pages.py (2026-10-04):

#!/usr/bin/env python3
# Copyright (c) Meta Platforms, Inc. and affiliates.
# SPDX-License-Identifier: Apache-2.0

"""Master site generator for Musedy AI Robot Companion.
Generates:
1. index.html - Meta Astryx Landing Page with interactive Robot Simulator
2. wiring.html - Interactive Pinout & Wiring Diagram with circuit highlights
3. deploy.html - Interactive Step-by-Step Deployment & Firmware Flashing Guide
Copies artifacts to both root / and docs/ for 100% GitHub Pages compatibility.
"""

import base64
from pathlib import Path
import subprocess

ROOT = Path(__file__).resolve().parents[1]
DOCS_DIR = ROOT / "docs"

# Load images
img_blue_path = ROOT / "docs/designs/xiaozhi_computer_blue.png"
img_astro_path = ROOT / "docs/designs/concept1_astropod.png"

b64_blue = base64.b64encode(img_blue_path.read_bytes()).decode("ascii") if img_blue_path.exists() else ""
b64_astro = base64.b64encode(img_astro_path.read_bytes()).decode("ascii") if img_astro_path.exists() else ""

SHARED_HEAD = '''
  <meta charset="utf-8">
  <meta name="viewport" content="width=device-width, initial-scale=1.0">
  <link rel="preconnect" href="https://fonts.googleapis.com">
  <link rel="preconnect" href="https://fonts.gstatic.com" crossorigin>
  <link href="https://fonts.googleapis.com/css2?family=Plus+Jakarta+Sans:wght@300;400;500;600;700;800&family=JetBrains+Mono:wght@400;500;600;700&display=swap" rel="stylesheet">
  <script src="https://cdn.tailwindcss.com"></script>
  <script>
    tailwind.config = {
      darkMode: 'class',
      theme: {
        extend: {
          fontFamily: {
            sans: ['"Plus Jakarta Sans"', '-apple-system', 'BlinkMacSystemFont', 'sans-serif'],
            mono: ['"JetBrains Mono"', 'monospace'],
          },
          colors: {
            astryx: {
              canvas: '#06080F',
              subtle: '#0D111D',
              surface: '#111726',
              elevated: '#172033',
              border: 'rgba(255, 255, 255, 0.08)',
              borderFocus: '#00F0FF',
              primary: '#00F0FF',
              secondary: '#2563EB',
              accent: '#00F0FF',
            }
          },
          boxShadow: {
            'glow-cyan': '0 0 35px -5px rgba(0, 240, 255, 0.35)',
            'glow-cobalt': '0 0 35px -5px rgba(37, 99, 235, 0.35)',
          }
        }
      }
    }
  </script>
  <style>
    :root {
      --astryx-cyan: #00F0FF;
      --astryx-cobalt: #2563EB;
      --astryx-bg: #06080F;
    }
    body {
      background-color: #06080F;
      color: #F8FAFC;
      font-family: 'Plus Jakarta Sans', sans-serif;
      overflow-x: hidden;
    }
    .astryx-mesh {
      background-image: 
        radial-gradient(circle at 50% 0%, rgba(0, 240, 255, 0.12) 0%, transparent 60%),
        radial-gradient(circle at 85% 30%, rgba(37, 99, 235, 0.12) 0%, transparent 50%),
        radial-gradient(circle at 15% 70%, rgba(56, 189, 248, 0.10) 0%, transparent 50%);
    }
    .astryx-grid {
      background-size: 40px 40px;
      background-image: 
        linear-gradient(to right, rgba(255, 255, 255, 0.03) 1px, transparent 1px),
        linear-gradient(to bottom, rgba(255, 255, 255, 0.03) 1px, transparent 1px);
    }
    .glass-card {
      background: rgba(17, 23, 38, 0.72);
      backdrop-filter: blur(16px);
      -webkit-backdrop-filter: blur(16px);
      border: 1px solid rgba(255, 255, 255, 0.08);
      transition: all 0.3s cubic-bezier(0.16, 1, 0.3, 1);
    }
    .glass-card:hover {
      border-color: rgba(0, 240, 255, 0.3);
      box-shadow: 0 12px 36px -10px rgba(0, 240, 255, 0.15);
    }
    .crt-screen {
      background: #020612;
      border: 3px solid #1E293B;
      box-shadow: inset 0 0 30px rgba(0, 240, 255, 0.15), 0 0 15px rgba(0, 240, 255, 0.2);
      position: relative;
    }
    .crt-screen::before {
      content: " ";
      display: block;
      position: absolute;
      top: 0; left: 0; bottom: 0; right: 0;
      background: linear-gradient(rgba(18, 16, 16, 0) 50%, rgba(0, 0, 0, 0.25) 50%), linear-gradient(90deg, rgba(255, 0, 0, 0.03), rgba(0, 255, 0, 0.01), rgba(0, 0, 255, 0.03));
      z-index: 10;
      background-size: 100% 3px, 6px 100%;
      pointer-events: none;
    }
    .text-balance {
      text-wrap: balance;
    }
    @keyframes wave {
      0%, 100% { height: 8px; }
      50% { height: 32px; }
    }
    .animate-wave {
      animation: wave 1.2s ease-in-out infinite;
    }
    @keyframes float {
      0%, 100% { transform: translateY(0px); }
      50% { transform: translateY(-10px); }
    }
    .animate-float {
      animation: float 6s ease-in-out infinite;
    }
  </style>
'''

NAV_HEADER = '''
  <!-- TOP STATUS BANNER (Meta Astryx Telemetry) -->
  <div class="border-b border-white/5 bg-black/40 backdrop-blur-md px-3 sm:px-4 py-1.5 text-xs font-mono text-slate-400">
    <div class="max-w-7xl mx-auto flex items-center justify-between">
      <div class="flex items-center space-x-2 sm:space-x-3">
        <span class="inline-flex items-center gap-1.5 shrink-0">
          <span class="h-2 w-2 rounded-full bg-emerald-400 animate-pulse"></span>
          <span class="text-emerald-400 font-semibold tracking-wider text-[11px] sm:text-xs">SYSTEM ONLINE</span>
        </span>
        <span class="text-white/20 hidden sm:inline">|</span>
        <span class="hidden sm:inline text-slate-400">CORE: ESP32-S3 DUAL-CORE 240MHz</span>
        <span class="hidden md:inline text-white/20">|</span>
        <span class="hidden md:inline text-slate-400">DISPLAY: 1.8" LANDSCAPE 160x128 (ST7735 / ST7789)</span>
      </div>
      <div class="flex items-center space-x-2 sm:space-x-4 shrink-0">
        <span class="text-cyan-400 text-[11px] sm:text-xs font-semibold">FW: v1.2-MUSEDY</span>
        <span class="text-white/20 hidden sm:inline">|</span>
        <a href="https://github.com/tody-agent/musedy" target="_blank" rel="noopener noreferrer" class="hover:text-cyan-300 transition-colors hidden sm:inline">GITHUB: tody-agent/musedy</a>
      </div>
    </div>
  </div>

  <!-- NAVIGATION HEADER -->
  <header class="sticky top-0 z-50 border-b border-white/10 bg-astryx-canvas/80 backdrop-blur-xl">
    <div class="max-w-7xl mx-auto px-4 sm:px-6 lg:px-8 h-16 flex items-center justify-between">
      <!-- Logo Brand -->
      <a href="index.html" class="flex items-center space-x-3 group shrink-0">
        <div class="w-9 h-9 rounded-xl bg-gradient-to-tr from-cyan-500 to-blue-600 flex items-center justify-center font-bold text-black text-lg shadow-glow-cyan">
          M
        </div>
        <div class="flex flex-col">
          <span class="font-extrabold text-base tracking-tight text-white group-hover:text-cyan-400 transition-colors">
            MUSEDY<span class="text-cyan-400 font-black">.S3</span>
          </span>
          <span class="text-[10px] font-mono tracking-widest text-slate-400 uppercase -mt-1">Retro AI Companion</span>
        </div>
      </a>

      <!-- Desktop Nav Links -->
      <nav class="hidden md:flex items-center space-x-1 lg:space-x-2 text-sm font-medium text-slate-300">
        <a href="index.html#showcase" class="px-3 py-1.5 rounded-lg hover:text-cyan-300 hover:bg-slate-800/60 transition-colors">01. Vỏ Máy Tính</a>
        <a href="index.html#simulator" class="px-3 py-1.5 rounded-lg hover:text-cyan-300 hover:bg-slate-800/60 transition-colors">02. Trải Nghiệm Giọng Nói</a>
        <a href="wiring.html" class="px-3 py-1.5 rounded-lg text-cyan-400 hover:text-cyan-300 hover:bg-slate-800/60 transition-colors">03. Sơ Đồ Kết Nối</a>
        <a href="deploy.html" class="px-3 py-1.5 rounded-lg text-sky-400 hover:text-sky-300 hover:bg-slate-800/60 transition-colors">04. Hướng Dẫn Triển Khai</a>
        <a href="index.html#specs" class="px-3 py-1.5 rounded-lg hover:text-cyan-300 hover:bg-slate-800/60 transition-colors">05. Thông Số STL</a>
      </nav>

      <!-- Action Buttons -->
      <div class="flex items-center space-x-2 sm:space-x-3">
        <a href="https://github.com/tody-agent/musedy" target="_blank" rel="noopener noreferrer" 
           class="hidden sm:inline-flex items-center gap-2 px-3.5 py-1.5 rounded-lg border border-white/15 bg-slate-800/40 text-xs font-semibold text-white hover:bg-slate-800 hover:border-cyan-400/50 hover:text-cyan-300 transition-all whitespace-nowrap">
          <svg class="w-4 h-4 text-cyan-400 shrink-0" fill="currentColor" viewBox="0 0 24 24"><path fill-rule="evenodd" d="M12 2C6.477 2 2 6.484 2 12.017c0 4.425 2.865 8.18 6.839 9.504.5.092.682-.217.682-.483 0-.237-.008-.868-.013-1.703-2.782.605-3.369-1.343-3.369-1.343-.454-1.158-1.11-1.466-1.11-1.466-.908-.62.069-.608.069-.608 1.003.07 1.53 1.032 1.53 1.032.892 1.53 2.341 1.088 2.91.832.092-.647.35-1.088.636-1.338-2.22-.253-4.555-1.113-4.555-4.951 0-1.093.39-1.988 1.029-2.688-.103-.253-.446-1.272.098-2.65 0 0 .84-.27 2.75 1.026A9.564 9.564 0 0112 6.844c.85.004 1.705.115 2.504.337 1.909-1.296 2.747-1.027 2.747-1.027.546 1.379.202 2.398.1 2.651.64.7 1.028 1.595 1.028 2.688 0 3.848-2.339 4.695-4.566 4.943.359.309.678.92.678 1.855 0 1.338-.012 2.419-.012 2.747 0 .268.18.58.688.482A10.019 10.019 0 0022 12.017C22 6.484 17.522 2 12 2z" clip-rule="evenodd"></path></svg>
          GitHub Repo
        </a>
        <a href="index.html#simulator" 
           class="inline-flex items-center gap-1.5 sm:gap-2 px-3 sm:px-4 py-2 rounded-xl border border-cyan-500/40 bg-cyan-500/10 text-xs font-bold text-cyan-300 hover:bg-cyan-500/20 active:scale-95 transition-all whitespace-nowrap shadow-glow-cyan">
          <svg class="w-4 h-4 shrink-0 text-cyan-400" fill="currentColor" viewBox="0 0 20 20"><path fill-rule="evenodd" d="M10 18a8 8 0 100-16 8 8 0 000 16zM9.555 7.168A1 1 0 008 8v4a1 1 0 001.555.832l3-2a1 1 0 000-1.664l-3-2z" clip-rule="evenodd"></path></svg>
          <span>Thử Ngay</span>
        </a>
      </div>
    </div>
  </header>
'''

SHARED_FOOTER = '''
  <!-- FOOTER -->
  <footer class="border-t border-white/10 py-12 bg-astryx-canvas text-xs text-slate-400">
    <div class="max-w-7xl mx-auto px-4 sm:px-6 lg:px-8 flex flex-col md:flex-row items-center justify-between gap-6">
      <!-- Brand & Copyright -->
      <div class="flex items-center space-x-3">
        <div class="w-7 h-7 rounded-lg bg-gradient-to-tr from-cyan-400 to-blue-500 flex items-center justify-center font-bold text-black text-sm">
          M
        </div>
        <div>
          <div class="text-white font-bold">MUSEDY S3 ROBOTICS</div>
          <div class="text-[11px] text-slate-400">Thiết kế bởi cộng đồng Maker • Mã nguồn mở theo giấy phép Apache-2.0</div>
        </div>
      </div>

      <!-- Links -->
      <div class="flex flex-wrap items-center gap-6 font-mono text-[11px]">
        <a href="wiring.html" class="hover:text-cyan-400 transition-colors">Sơ Đồ Kết Nối</a>
        <a href="deploy.html" class="hover:text-cyan-400 transition-colors">Hướng Dẫn Triển Khai</a>
        <a href="https://github.com/tody-agent/musedy" target="_blank" rel="noopener noreferrer" class="hover:text-cyan-400 transition-colors">GitHub Repository</a>
        <span class="text-white/20">|</span>
        <span class="text-cyan-300">OpenDesign &amp; Meta Astryx System</span>
      </div>
    </div>
  </footer>
'''

def generate_index_html():
    return f'''<!DOCTYPE html>
<html lang="vi" class="scroll-smooth">
<head>
  {SHARED_HEAD}
  <title>Musedy S3 • Robot Trí Tuệ Nhân Tạo Mini (Meta Astryx Edition)</title>
  <meta name="description" content="Robot Trí Tuệ Nhân Tạo Mini Musedy phong cách Máy Tính Cổ Điển Thập Niên 80 chạy ESP32-S3, màn hình màu tròn CRT, Voice Wakeup và tiếng Việt mượt mà.">
</head>
<body class="astryx-mesh astryx-grid min-h-screen antialiased selection:bg-cyan-500 selection:text-black">
  {NAV_HEADER}

  <!-- HERO SECTION -->
  <section id="hero" data-od-id="hero-section" class="relative pt-10 pb-16 md:pt-20 md:pb-32 overflow-hidden">
    <div class="max-w-7xl mx-auto px-4 sm:px-6 lg:px-8">
      <div class="grid grid-cols-1 lg:grid-cols-12 gap-10 lg:gap-12 items-center">
        
        <!-- Left Column: Copy & Value Proposition -->
        <div class="lg:col-span-7 flex flex-col space-y-6 text-left">
          
          <!-- Badge -->
          <div class="inline-flex items-center gap-2 px-3 py-1 rounded-full border border-cyan-500/30 bg-cyan-950/40 text-cyan-300 text-xs font-mono tracking-wider w-fit">
            <span class="inline-block w-2 h-2 rounded-full bg-cyan-400 animate-ping"></span>
            MUSEDY AI ROBOT • META ASTRYX DESIGN SYSTEM
          </div>

          <!-- Main Heading -->
          <h1 class="text-3xl sm:text-5xl lg:text-6xl font-extrabold tracking-tight text-white leading-[1.15] text-balance">
            Robot Trí Tuệ Nhân Tạo <br>
            <span class="text-transparent bg-clip-text bg-gradient-to-r from-cyan-400 via-sky-300 to-blue-500">
              Musedy Máy Tính Mini
            </span>
          </h1>

          <!-- Subheading -->
          <p class="text-sm sm:text-base lg:text-lg text-slate-300 font-normal leading-relaxed max-w-2xl text-balance">
            Sự hội ngộ giữa hình hài máy tính <strong>Macintosh CRT thập niên 80</strong> màu Xanh Dương và bộ não trí tuệ nhân tạo thế hệ mới <strong>ESP32-S3</strong>: Voice Wakeup kích hoạt tức thì, giao tiếp tiếng Việt tự nhiên, màn hình màu tròn vintage và loa vòm đánh gầm 3W.
          </p>

          <!-- Key Metrics Pills -->
          <div class="grid grid-cols-3 gap-2 sm:gap-3 pt-2 max-w-lg w-full">
            <div class="glass-card p-2.5 sm:p-3 rounded-xl border border-white/10 text-center">
              <div class="text-lg sm:text-2xl font-black text-cyan-400 font-mono">0ms</div>
              <div class="text-[10px] sm:text-[11px] text-slate-400 font-medium whitespace-nowrap">Chi Phí TTS</div>
            </div>
            <div class="glass-card p-2.5 sm:p-3 rounded-xl border border-white/10 text-center">
              <div class="text-lg sm:text-2xl font-black text-sky-400 font-mono">30 FPS</div>
              <div class="text-[10px] sm:text-[11px] text-slate-400 font-medium whitespace-nowrap">Màn Hình SPI</div>
            </div>
            <div class="glass-card p-2.5 sm:p-3 rounded-xl border border-white/10 text-center">
              <div class="text-lg sm:text-2xl font-black text-blue-400 font-mono">&lt;280ms</div>
              <div class="text-[10px] sm:text-[11px] text-slate-400 font-medium whitespace-nowrap">Phản Hồi VAD</div>
            </div>
          </div>

          <!-- Dual CTAs -->
          <div class="flex flex-col sm:flex-row items-stretch sm:items-center gap-3 sm:gap-4 pt-4 w-full sm:w-auto">
            <a href="https://makerworld.com/en/models/1967811-xiaozhi-ai-computer-xiaozhi#profileId-2115633" target="_blank" rel="noopener noreferrer"
               class="justify-center px-5 sm:px-6 py-3.5 rounded-xl bg-gradient-to-r from-cyan-400 to-blue-500 font-bold text-black text-xs sm:text-sm shadow-glow-cyan hover:shadow-cyan-500/50 hover:brightness-110 active:scale-95 transition-all inline-flex items-center gap-2">
              <svg class="w-5 h-5 shrink-0" fill="none" stroke="currentColor" viewBox="0 0 24 24"><path stroke-linecap="round" stroke-linejoin="round" stroke-width="2" d="M7 16a4 4 0 01-.88-7.903A5 5 0 1115.9 6L16 6a5 5 0 011 9.9M9 19l3 3m0 0l3-3m-3 3V10"></path></svg>
              <span>Tải File In 3D (MakerWorld)</span>
            </a>
            <a href="#simulator" 
               class="justify-center px-5 sm:px-6 py-3.5 rounded-xl border border-white/20 bg-white/5 font-semibold text-white text-xs sm:text-sm hover:bg-white/10 hover:border-cyan-400/60 active:scale-95 transition-all inline-flex items-center gap-2">
              <svg class="w-5 h-5 text-cyan-400 shrink-0" fill="none" stroke="currentColor" viewBox="0 0 24 24"><path stroke-linecap="round" stroke-linejoin="round" stroke-width="2" d="M14.752 11.168l-3.197-2.132A1 1 0 0010 9.87v4.263a1 1 0 001.555.832l3.197-2.132a1 1 0 000-1.664z"></path><path stroke-linecap="round" stroke-linejoin="round" stroke-width="2" d="M21 12a9 9 0 11-18 0 9 9 0 0118 0z"></path></svg>
              <span>Trải Nghiệm Giọng Nói Musedy</span>
            </a>
          </div>

          <!-- Verified Hardware compatibility note -->
          <div class="flex items-center gap-3 pt-2 text-xs text-slate-400 font-mono">
            <span class="inline-block w-2 h-2 rounded-full bg-cyan-400"></span>
            <span>Màn hình 1.8" xoay ngang 160x128 ST7735 (Chuẩn Vỏ Retro) &amp; tùy chọn 1.28" Tròn (GC9A01)</span>
          </div>

        </div>

        <!-- Right Column: Photorealistic Hero Render Showcase -->
        <div class="lg:col-span-5 relative flex justify-center items-center">
          <div class="absolute -inset-4 bg-gradient-to-tr from-cyan-500/20 via-blue-500/10 to-blue-600/20 rounded-3xl blur-3xl -z-10 animate-pulse-slow"></div>

          <div class="relative glass-card rounded-3xl p-4 border border-white/15 shadow-2xl animate-float">
            <div class="flex items-center justify-between pb-3 mb-3 border-b border-white/10 text-xs font-mono text-slate-400">
              <span class="flex items-center gap-2">
                <span class="w-2.5 h-2.5 rounded-full bg-cyan-400"></span>
                <span class="text-white font-semibold">MUSEDY COMPUTER EDITION</span>
              </span>
              <span class="bg-cyan-500/10 text-cyan-300 px-2 py-0.5 rounded border border-cyan-500/20 text-[10px]">COLOR: BLUE/CREAM</span>
            </div>

            <div class="relative overflow-hidden rounded-2xl bg-gradient-to-b from-slate-900/90 to-black border border-white/10 group">
              <img id="hero-showcase-img" 
                   src="data:image/png;base64,{b64_blue}" 
                   alt="Musedy S3 Retro Computer Blue Edition" 
                   class="w-full h-auto object-cover rounded-2xl transition-transform duration-700 group-hover:scale-105">
              
              <div class="absolute bottom-6 right-6 glass-card px-3 py-1.5 rounded-lg border border-white/20 text-[11px] font-mono text-slate-300 flex items-center gap-2 shadow-lg backdrop-blur-md">
                <span class="w-1.5 h-1.5 rounded-full bg-cyan-400 animate-ping"></span>
                <span>Floppy Slot (Khe đĩa mềm)</span>
              </div>

              <div class="absolute top-6 left-6 glass-card px-3 py-1.5 rounded-lg border border-white/20 text-[11px] font-mono text-slate-300 flex items-center gap-2 shadow-lg backdrop-blur-md">
                <span class="w-1.5 h-1.5 rounded-full bg-blue-400"></span>
                <span>4 Phím cứng xúc giác đỉnh</span>
              </div>
            </div>

            <div class="mt-4 pt-3 border-t border-white/10 flex items-center justify-between text-xs text-slate-400 font-mono">
              <span>DESIGN: 董老爺 (Mr. Dong)</span>
              <span class="text-cyan-400">MAKERWORLD #1967811</span>
            </div>
          </div>
        </div>

      </div>
    </div>
  </section>

  <!-- INTERACTIVE VIRTUAL MUSEDY SIMULATOR -->
  <section id="simulator" data-od-id="simulator-section" class="py-16 md:py-24 border-y border-white/10 bg-astryx-subtle/60 relative">
    <div class="max-w-7xl mx-auto px-4 sm:px-6 lg:px-8">
      
      <div class="text-center max-w-3xl mx-auto mb-12">
        <div class="inline-flex items-center gap-2 px-3 py-1 rounded-full border border-blue-500/30 bg-blue-950/40 text-blue-300 text-xs font-mono tracking-wider mb-3">
          LIVE INTERACTIVE SIMULATOR
        </div>
        <h2 class="text-3xl sm:text-4xl font-extrabold text-white tracking-tight text-balance">
          Trải Nghiệm Màn Hình Cảm Xúc &amp; Giọng Nói Musedy S3
        </h2>
        <p class="mt-3 text-slate-300 text-sm sm:text-base text-balance">
          Nhấp vào các trạng thái cảm xúc để quan sát đôi mắt robot biến đổi trên màn hình CRT ảo, hoặc nhấp vào các câu thoại mẫu để nghe thử giọng nói tiếng Việt mượt mà!
        </p>
      </div>

      <div class="grid grid-cols-1 lg:grid-cols-12 gap-8 items-center">
        <!-- Virtual Monitor -->
        <div class="lg:col-span-6 flex flex-col items-center">
          <div class="w-full max-w-md p-6 glass-card rounded-3xl border border-white/15 shadow-2xl relative">
            <div class="flex items-center justify-between pb-3 mb-3 border-b border-white/10 text-xs font-mono text-slate-400">
              <span class="flex items-center gap-2">
                <span class="h-2 w-2 rounded-full bg-cyan-400 animate-pulse"></span>
                <span id="sim-status-label" class="text-cyan-300 font-bold uppercase">待命 • STANDBY</span>
              </span>
              <div class="flex items-center gap-3">
                <span id="sim-wifi-icon">📶 WI-FI</span>
                <span>🔋 100%</span>
              </div>
            </div>

            <!-- Display Form Factor Switcher -->
            <div class="flex items-center gap-1.5 p-1 bg-black/40 border border-white/10 rounded-xl mb-4 text-[11px] font-mono">
              <button id="btn-mode-18" onclick="setDisplayMode('18landscape')" class="flex-1 py-1.5 px-2 rounded-lg bg-cyan-500/20 text-cyan-300 font-semibold border border-cyan-500/40 transition-all flex items-center justify-center gap-1.5">
                <span>🖥️ 1.8" Ngang (160x128)</span>
              </button>
              <button id="btn-mode-round" onclick="setDisplayMode('round')" class="flex-1 py-1.5 px-2 rounded-lg text-slate-400 hover:text-white transition-all flex items-center justify-center gap-1.5">
                <span>🐾 1.28" Tròn (240x240)</span>
              </button>
            </div>
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

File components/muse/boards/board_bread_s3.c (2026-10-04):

/*
 * Copyright (c) Meta Platforms, Inc. and affiliates.
 *
 * Licensed under the Apache License, Version 2.0 (the "License");
 * you may not use this file except in compliance with the License.
 * You may obtain a copy of the License at
 *
 *     http://www.apache.org/licenses/LICENSE-2.0
 *
 * Unless required by applicable law or agreed to in writing, software
 * distributed under the License is distributed on an "AS IS" BASIS,
 * WITHOUT WARRANTIES OR CONDITIONS OF ANY KIND, either express or implied.
 * See the License for the specific language governing permissions and
 * limitations under the License.
 */

/*
 * Rody S3 Round Pet (ESP32-S3 N16R8):
 * - Round 1.28" 240x240 GC9A01 SPI IPS LCD (Full RGB565 color with circular bezel ring)
 * - Backlight PWM on GPIO21 (LEDC smooth dimming)
 * - Micro INMP441 (I2S0 RX) and Ampli MAX98357A (I2S1 TX) simplex audio (no codec needed)
 * - Pet Head Touch sensor on GPIO2 (capacitive pad with multi-cycle glitch filter)
 * - MPU6050 Motion / Shake / Fall IMU on I2C (SDA=8, SCL=9)
 * - Buttons: BOOT (GPIO0 Talk) and GPIO47 (Aux/Menu)
 * - Onboard RGB LED WS2812 on GPIO48
 */

#include <math.h>
#include <string.h>
#include "driver/gpio.h"
#include "driver/i2c_master.h"
#include "driver/i2s_std.h"
#include "driver/ledc.h"
#include "driver/spi_master.h"
#include "esp_check.h"
#include "esp_heap_caps.h"
#include "esp_lcd_panel_io.h"
#include "esp_lcd_panel_ops.h"
#include "esp_log.h"
#include "esp_lv_adapter.h"
#include "esp_sleep.h"
#include "freertos/FreeRTOS.h"
#include "freertos/task.h"

#include "esp_lcd_panel_gc9a01.h"
#include "esp_lcd_panel_st7735.h"
#include "muse_audio.h"
#include "muse_board.h"
#include "muse_mem.h"
#include "muse_state.h"

static const char *TAG = "board";

#define LCD_RES 240

#if defined(CONFIG_MUSE_DISPLAY_GC9A01_ROUND)
#define LCD_WIDTH 240
#define LCD_HEIGHT 240
#define LCD_IS_ROUND true
#define LCD_DIAGONAL 1.28f
#define BOARD_NAME "Musedy S3 Round Pet"
#define LCD_TALK_HINT_ALIGN LV_ALIGN_BOTTOM_RIGHT
#define LCD_TALK_HINT_X -12
#define LCD_TALK_HINT_Y -12
#define LCD_AUX_HINT_ALIGN LV_ALIGN_BOTTOM_LEFT
#define LCD_AUX_HINT_X 12
#define LCD_AUX_HINT_Y -12
#else
// Default: 1.8" 160x128 Landscape ST7735/ST7789 (Retro Computer Edition)
#define LCD_WIDTH 160
#define LCD_HEIGHT 128
#define LCD_IS_ROUND false
#define LCD_DIAGONAL 1.8f
#define BOARD_NAME "Musedy S3 Retro Computer (1.8\" Landscape)"
#define LCD_TALK_HINT_ALIGN LV_ALIGN_BOTTOM_RIGHT
#define LCD_TALK_HINT_X -6
#define LCD_TALK_HINT_Y -4
#define LCD_AUX_HINT_ALIGN LV_ALIGN_BOTTOM_LEFT
#define LCD_AUX_HINT_X 6
#define LCD_AUX_HINT_Y -4
#endif

#define LCD_HOST SPI2_HOST
#define LCD_SCLK GPIO_NUM_42
#define LCD_MOSI GPIO_NUM_41
#define LCD_DC GPIO_NUM_40
#define LCD_RST GPIO_NUM_39
#define LCD_CS GPIO_NUM_38
#define LCD_BL GPIO_NUM_21
#define DRAW_BUF_LINES 32

#define I2C_SDA GPIO_NUM_8
#define I2C_SCL GPIO_NUM_9
#define MPU6050_ADDR 0x68

#define MIC_WS GPIO_NUM_4
#define MIC_SCK GPIO_NUM_5
#define MIC_DIN GPIO_NUM_6
#define SPK_DOUT GPIO_NUM_7
#define SPK_BCLK GPIO_NUM_15
#define SPK_LRCK GPIO_NUM_16
#define MIC_SHIFT 12               /* 24-bit INMP441 MSB in 32-bit slot -> 16-bit PCM */
#define MIC_GAIN_OFFSET_DB 30      /* Muse default 30 dB = unity gain (x1) */

#define TALK_GPIO GPIO_NUM_0       /* BOOT button */
#define AUX_GPIO GPIO_NUM_47       /* Auxiliary / Menu button */
#define TOUCH_GPIO GPIO_NUM_2      /* Pet Head Touch Sensor (TTP223 / Capacitive Pad) */

static i2c_master_bus_handle_t s_i2c;
static esp_lcd_panel_io_handle_t s_io;
static esp_lcd_panel_handle_t s_panel;
static muse_gpio_button_t s_talk, s_aux;
static i2s_chan_handle_t s_rx, s_tx;
static bool s_mic_on;
static bool s_spk_on;
static int s_mic_gain_q8 = 256;
static bool s_has_imu = false;
static i2c_master_dev_handle_t s_mpu = NULL;
static bool s_touch_was_pressed = false;
static int64_t s_last_imu_poll_us = 0;
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

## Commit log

2026-10-04 feat: initial commit of Musedy S3 - Retro AI Robot Companion firmware, landing page, wiring diagram and deployment docs
    [obj_1_组合体.stl, obj_2_Object_1.stl, obj_3_Object_4.stl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]
2026-10-04 feat(display): switch to 1.8 inch landscape 160x128 ST7735 for computer case
    - Added esp_lcd_panel_st7735.c and .h with native ESP-IDF esp_lcd support
    - Updated board_bread_s3.c with 1.8" 160x128 landscape mode and ST7735/ST7789 driver
    - Added CONFIG_MUSE_DISPLAY_180_LANDSCAPE option to Kconfig and sdkconfig presets
    - Created devices/sdkconfig.muse-computer-18 dedicated profile
    - Designed cad/musedy_computer_18_adapter.scad and built binary STL in cad/stl/
    - Updated web pages (index, wiring, deploy) and docs with 1.8" landscape pinout
    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
    [musedy_computer_18_adapter.scad, musedy_computer_18_adapter.stl]
2026-10-04 feat(web): add interactive display switcher (1.8" Landscape vs 1.28" Round) and update CHANGELOG to v1.6.0
